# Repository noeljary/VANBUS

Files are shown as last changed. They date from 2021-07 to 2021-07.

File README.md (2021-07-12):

# VANBUS
Circuits and MCU Code for Camper Van Electronics Control Systems

VANBUS will be a series of circuit boards designed to control all electronic systems within a camper van conversion. It is based on a CANBUS network for inter-board communiciations.

This repository contains the Autodesk EAGLE files for the circuit boards, links to the custom designed cases, and the microcontroller code used to control the system.

Boards:
- LIGHTING_CTL_BOARD: Circuit Board for PWM Control of LED Lighting
- MOSFET_CTL_BOARD: Circuit Board for Fused Power Distribution with Voltage/Current per Channel Monitoring
- REMOTE_SWITCH_BOARD: Circuit Board for Remote Switching of MOSFET/Lighting Circuits with Momentary/Latched Switching, and Status Indication
- CAPACITIVE_SWITCH_BOARD: Circuit Board for Dimming Control of Lighting Circuits with Capacitive Touch Slider
- MOSFET_POC: Proof of Concept Circuit Board for MOSET based solid state relay system
- VANBUS_HUB: Circuit Board for Central Connection of CANBUS connectors where daisy chaining is not possible

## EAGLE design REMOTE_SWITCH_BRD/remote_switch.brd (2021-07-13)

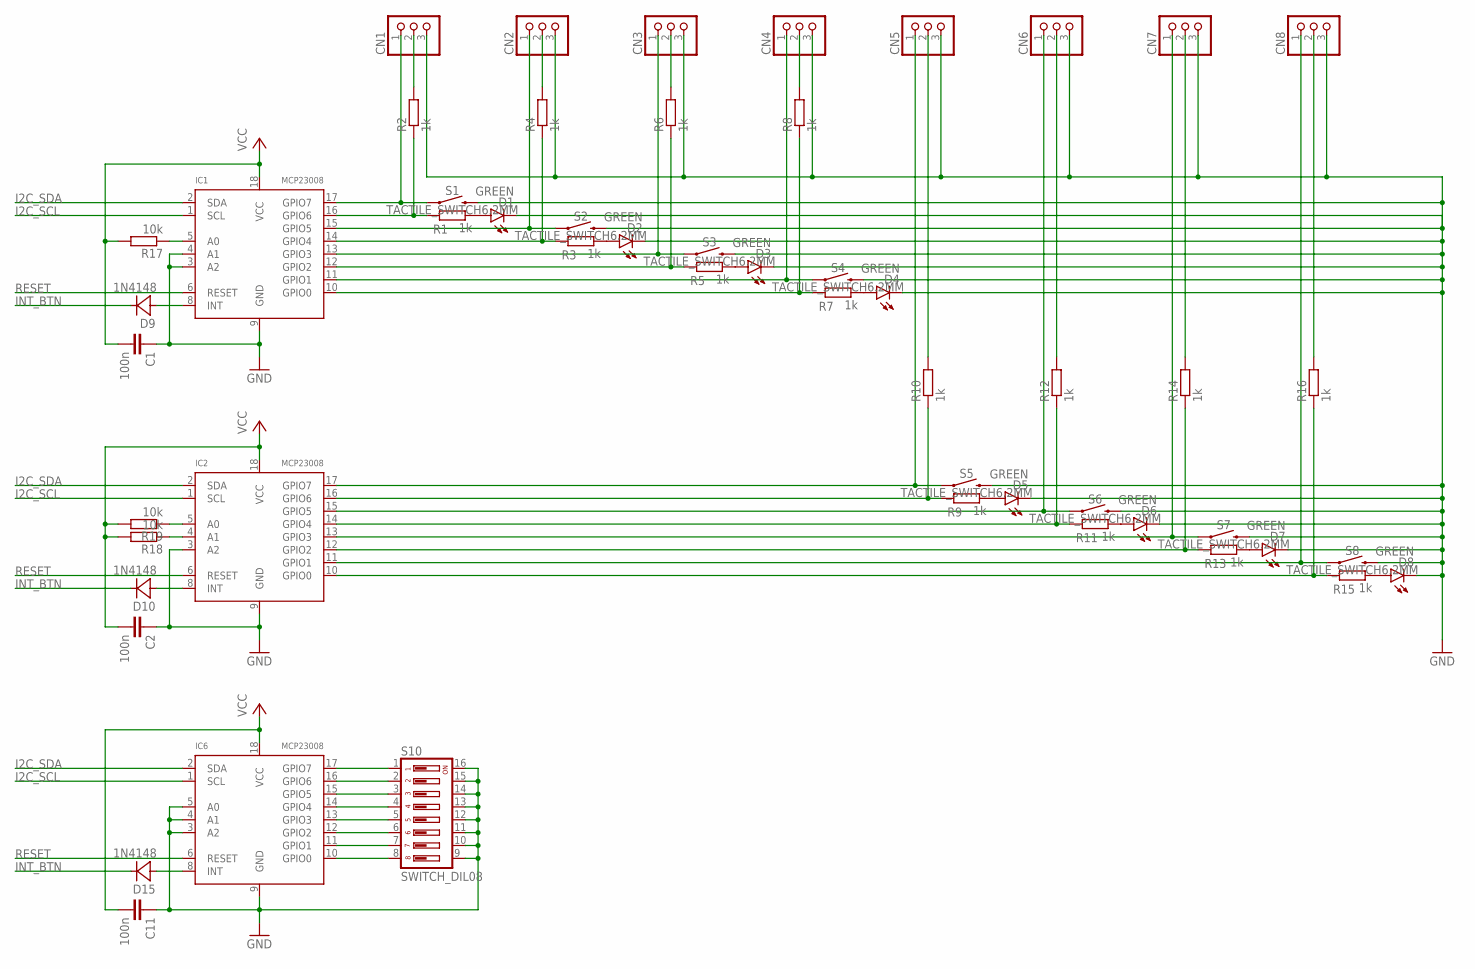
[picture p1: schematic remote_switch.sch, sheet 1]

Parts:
C1, C2, C11: 100n; C0805
CN1, CN2, CN3, CN4, CN5, CN6, CN7, CN8: JST_3PIN; JSTPH3
D1, D2, D3, D4, D5, D6, D7, D8: GREEN; CHIPLED_1206
D9, D10, D15: 1N4148; SOD123
IC1, IC2, IC6: MCP23008; SO18W
R1, R2, R3, R4, R5, R6, R7, R8, R9, R10, R11, R12, R13, R14, R15, R16: 1k; R0805
R17, R18, R19: 10k; R0805
S1, S2, S3, S4, S5, S6, S7, S8: TACTILE_SWITCH6.2MM; TACTILE_SWITCH_SMD_6.2MM
S10: SWITCH_DIL08; CTS-219-08

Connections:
GND: C1.1, C2.1, C11.1, CN1.3, CN2.3, CN3.3, CN4.3, CN5.3, CN6.3, CN7.3, CN8.3, D1.C, D2.C, D3.C, D4.C, D5.C, D6.C, D7.C, D8.C, IC1.3 (A2), IC1.4 (A1), IC1.9 (GND), IC2.3 (A2), IC2.9 (GND), IC6.3 (A2), IC6.4 (A1), IC6.5 (A0), IC6.9 (GND), S1.B1 (2), S1.B2 (2), S2.B1 (2), S2.B2 (2), S3.B1 (2), S3.B2 (2), S4.B1 (2), S4.B2 (2), S5.B1 (2), S5.B2 (2), S6.B1 (2), S6.B2 (2), S7.B1 (2), S7.B2 (2), S8.B1 (2), S8.B2 (2), S10.9, S10.10, S10.11, S10.12, S10.13, S10.14, S10.15, S10.16; also elsewhere on the board
I2C_SCL: IC1.1 (SCL), IC2.1 (SCL), IC6.1 (SCL); also elsewhere on the board
I2C_SDA: IC1.2 (SDA), IC2.2 (SDA), IC6.2 (SDA); also elsewhere on the board
INT_BTN: D9.C, D10.C, D15.C; also elsewhere on the board
unnamed: IC1.5 (A0), R17.1
unnamed: IC2.5 (A0), R19.1
unnamed: IC2.4 (A1), R18.1
unnamed: IC6.17 (GPIO7), S10.1
unnamed: IC6.16 (GPIO6), S10.2
unnamed: IC6.15 (GPIO5), S10.3
unnamed: IC6.14 (GPIO4), S10.4
unnamed: IC6.13 (GPIO3), S10.5
unnamed: IC6.12 (GPIO2), S10.6
unnamed: IC6.11 (GPIO1), S10.7
unnamed: CN1.1, IC1.17 (GPIO7), S1.A1 (1), S1.A2 (1)
unnamed: CN2.1, IC1.15 (GPIO5), S2.A1 (1), S2.A2 (1)
unnamed: CN3.1, IC1.13 (GPIO3), S3.A1 (1), S3.A2 (1)
unnamed: CN4.1, IC1.11 (GPIO1), S4.A1 (1), S4.A2 (1)
unnamed: CN5.1, IC2.17 (GPIO7), S5.A1 (1), S5.A2 (1)
unnamed: CN6.1, IC2.15 (GPIO5), S6.A1 (1), S6.A2 (1)
unnamed: CN7.1, IC2.13 (GPIO3), S7.A1 (1), S7.A2 (1)
unnamed: CN8.1, IC2.11 (GPIO1), S8.A1 (1), S8.A2 (1)
unnamed: D1.A, R1.2
unnamed: D2.A, R3.2
unnamed: D3.A, R5.2
unnamed: D4.A, R7.2
unnamed: D5.A, R9.2
unnamed: D6.A, R11.2
unnamed: D7.A, R13.2
unnamed: D8.A, R15.2
unnamed: CN1.2, R2.2
unnamed: IC1.16 (GPIO6), R1.1, R2.1
unnamed: CN2.2, R4.2
unnamed: CN3.2, R6.2
unnamed: CN4.2, R8.2
unnamed: CN5.2, R10.2
unnamed: CN6.2, R12.2
unnamed: CN7.2, R14.2
unnamed: CN8.2, R16.2
unnamed: IC1.14 (GPIO4), R3.1, R4.1
unnamed: IC1.12 (GPIO2), R5.1, R6.1
unnamed: IC1.10 (GPIO0), R7.1, R8.1
unnamed: IC2.16 (GPIO6), R9.1, R10.1
unnamed: IC2.14 (GPIO4), R11.1, R12.1
unnamed: IC2.12 (GPIO2), R13.1, R14.1
unnamed: IC2.10 (GPIO0), R15.1, R16.1
unnamed: IC6.10 (GPIO0), S10.8
unnamed: D10.A, IC2.8 (INT)
unnamed: D9.A, IC1.8 (INT)
unnamed: D15.A, IC6.8 (INT)
RESET: IC1.6 (RESET), IC2.6 (RESET), IC6.6 (RESET); also elsewhere on the board
VCC: C1.2, C2.2, C11.2, IC1.18 (VCC), IC2.18 (VCC), IC6.18 (VCC), R17.2, R18.2, R19.2; also elsewhere on the board

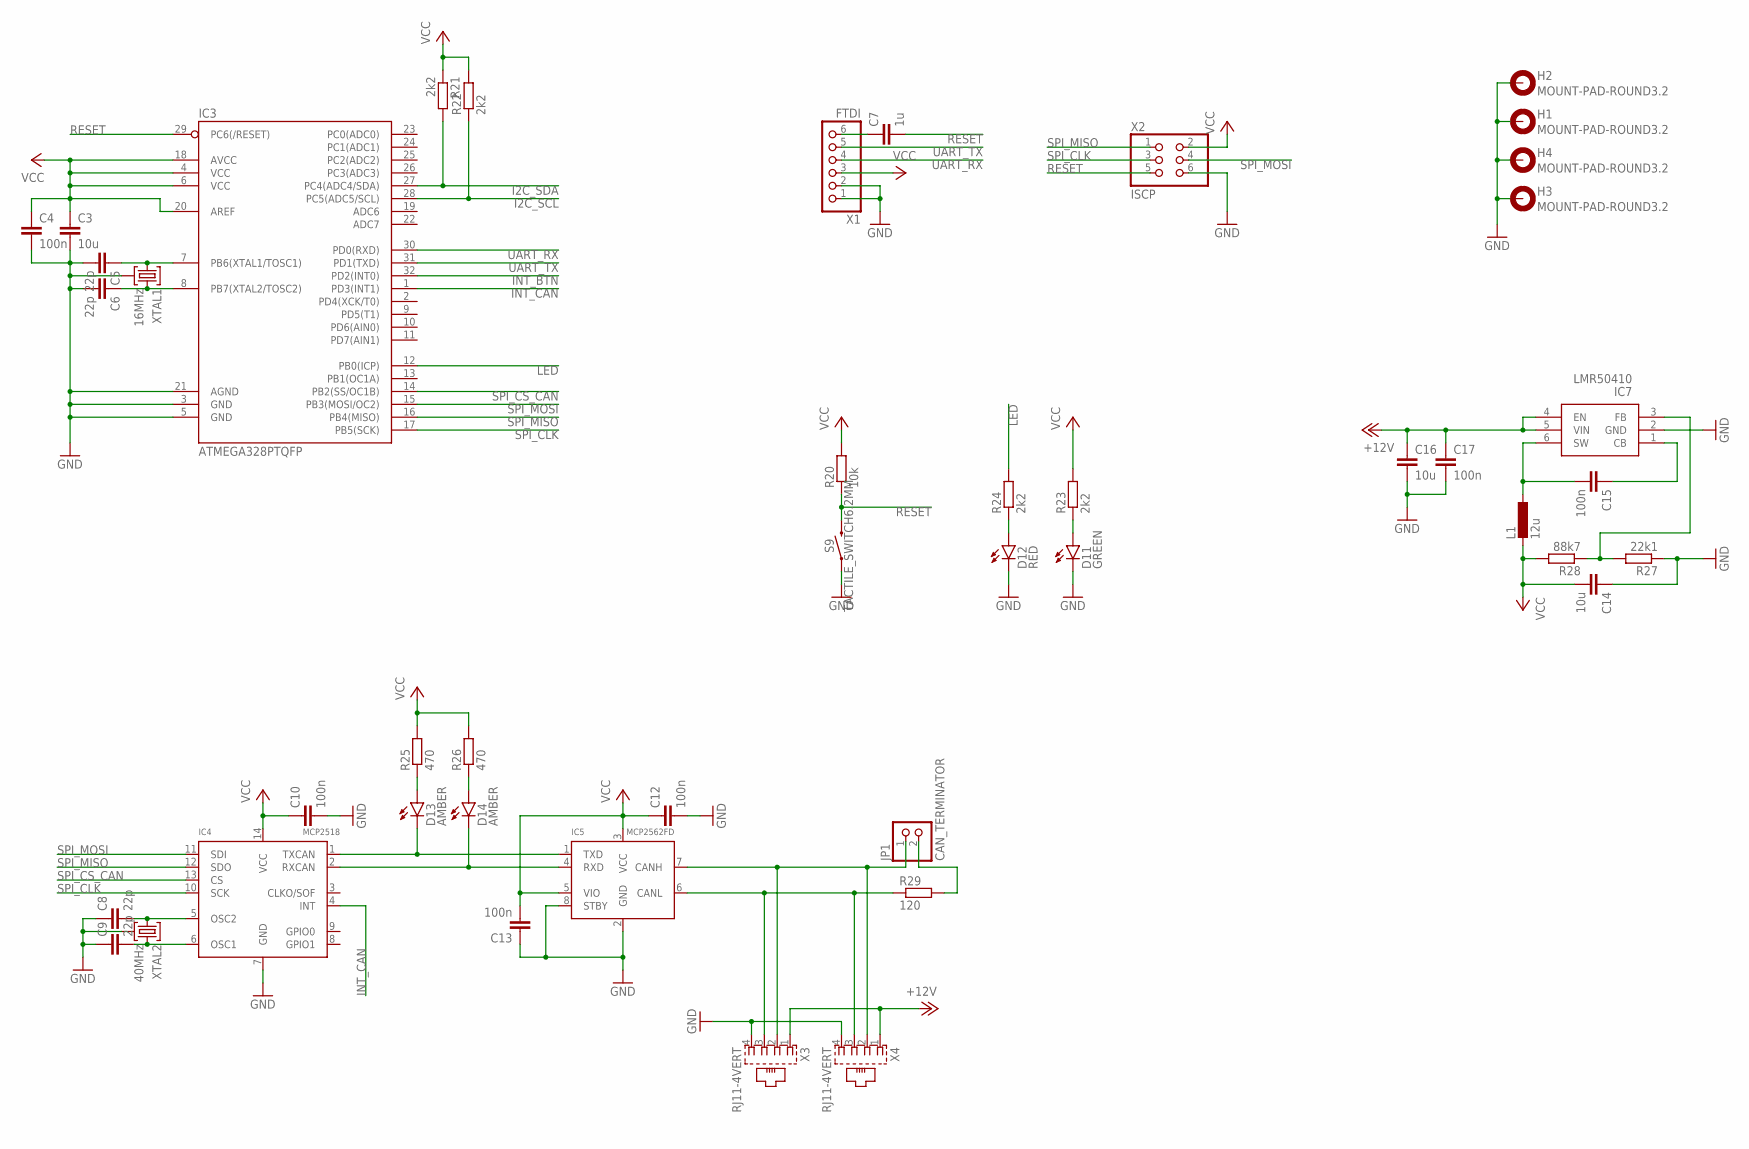
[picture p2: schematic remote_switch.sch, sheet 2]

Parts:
C3, C14, C16: 10u; C1206
C4, C10, C12, C13, C15, C17: 100n; C0805
C5, C6, C8, C9: 22p; C0805
C7: 1u; C0805
D11: GREEN; CHIPLED_1206
D12: RED; CHIPLED_1206
D13, D14: AMBER; CHIPLED_1206
H1, H2, H3, H4: MOUNT-PAD-ROUND3.2; 3,2-PAD
IC3: ATMEGA328PTQFP; TQFP32_0.8MM_7X7MM
IC4: MCP2518; SO14
IC5: MCP2562FD; SO08
IC7: LMR50410; SOT23-6
JP1: CAN_TERMINATOR; 1X02
L1: 12u; L_7.3MM
R20: 10k; R0805
R21, R22, R23, R24: 2k2; R0805
R25, R26: 470; R0805
R27: 22k1; R0805
R28: 88k7; R0805
R29: 120; R0805
S9: TACTILE_SWITCH6.2MM; TACTILE_SWITCH_SMD_6.2MM
X1: FTDI; 1X06
X2: ISCP; 2X03
X3, X4: RJ11-4VERT; RJ11-4_VERT
XTAL1: 16MHz; XTAL_5.0X3.2_4
XTAL2: 40MHz; XTAL_5.0X3.2_4

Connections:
+12V: C16.1, C17.1, IC7.4 (EN), IC7.5 (VIN), X3.1, X4.1
GND: C3.2, C4.2, C5.2, C6.2, C8.1, C9.1, C10.2, C12.2, C13.1, C14.1, C16.2, C17.2, D11.C, D12.C, H1.B3,2, H1.P$1, H1.P$2, H1.P$3, H1.P$4, H1.P$5, H1.P$6, H1.P$7, H1.P$8, H2.B3,2, H2.P$1, H2.P$2, H2.P$3, H2.P$4, H2.P$5, H2.P$6, H2.P$7, H2.P$8, H3.B3,2, H3.P$1, H3.P$2, H3.P$3, H3.P$4, H3.P$5, H3.P$6, H3.P$7, H3.P$8, H4.B3,2, H4.P$1, H4.P$2, H4.P$3, H4.P$4, H4.P$5, H4.P$6, H4.P$7, H4.P$8, IC3.3 (GND), IC3.5 (GND), IC3.21 (AGND), IC4.7 (GND), IC5.2 (GND), IC5.8 (STBY), IC7.2 (GND), R27.1, S9.A1 (1), S9.A2 (1), X1.1, X1.2, X2.6, X3.4, X4.4, XTAL1.2, XTAL1.4 (2), XTAL2.2, XTAL2.4 (2); also elsewhere on the board
I2C_SCL: IC3.28 (PC5(ADC5/SCL)), R22.1; also elsewhere on the board
I2C_SDA: IC3.27 (PC4(ADC4/SDA)), R21.2; also elsewhere on the board
INT_BTN: IC3.32 (PD2(INT0)); also elsewhere on the board
INT_CAN: IC3.1 (PD3(INT1)), IC4.4 (INT)
LED: IC3.12 (PB0(ICP)), R24.2
unnamed: D12.A, R24.1
unnamed: C5.1, IC3.7 (PB6(XTAL1/TOSC1)), XTAL1.1
unnamed: C6.1, IC3.8 (PB7(XTAL2/TOSC2)), XTAL1.3
unnamed: D11.A, R23.1
unnamed: C7.1, X1.6
unnamed: IC5.6 (CANL), R29.1, X3.3, X4.3
unnamed: IC5.7 (CANH), JP1.1, X3.2, X4.2
unnamed: D13.C, IC4.1 (TXCAN), IC5.1 (TXD)
unnamed: D14.C, IC4.2 (RXCAN), IC5.4 (RXD)
unnamed: C8.2, IC4.5 (OSC2), XTAL2.1
unnamed: C9.2, IC4.6 (OSC1), XTAL2.3
unnamed: D13.A, R25.1
unnamed: D14.A, R26.1
unnamed: JP1.2, R29.2
unnamed: C15.2, IC7.6 (SW), L1.1
unnamed: C15.1, IC7.1 (CB)
unnamed: IC7.3 (FB), R27.2, R28.1
RESET: C7.2, IC3.29 (PC6(/RESET)), R20.1, S9.B1 (2), S9.B2 (2), X2.5; also elsewhere on the board
SPI_CLK: IC3.17 (PB5(SCK)), IC4.10 (SCK), X2.3
SPI_CS_CAN: IC3.14 (PB2(SS/OC1B)), IC4.13 (CS)
SPI_MISO: IC3.16 (PB4(MISO)), IC4.12 (SDO), X2.1
SPI_MOSI: IC3.15 (PB3(MOSI/OC2)), IC4.11 (SDI), X2.4
UART_RX: IC3.30 (PD0(RXD)), X1.4
UART_TX: IC3.31 (PD1(TXD)), X1.5
VCC: C3.1, C4.1, C10.1, C12.1, C13.2, C14.2, IC3.4 (VCC), IC3.6 (VCC), IC3.18 (AVCC), IC3.20 (AREF), IC4.14 (VCC), IC5.3 (VCC), IC5.5 (VIO), L1.2, R20.2, R21.1, R22.2, R23.2, R25.2, R26.2, R28.2, X1.3, X2.2; also elsewhere on the board

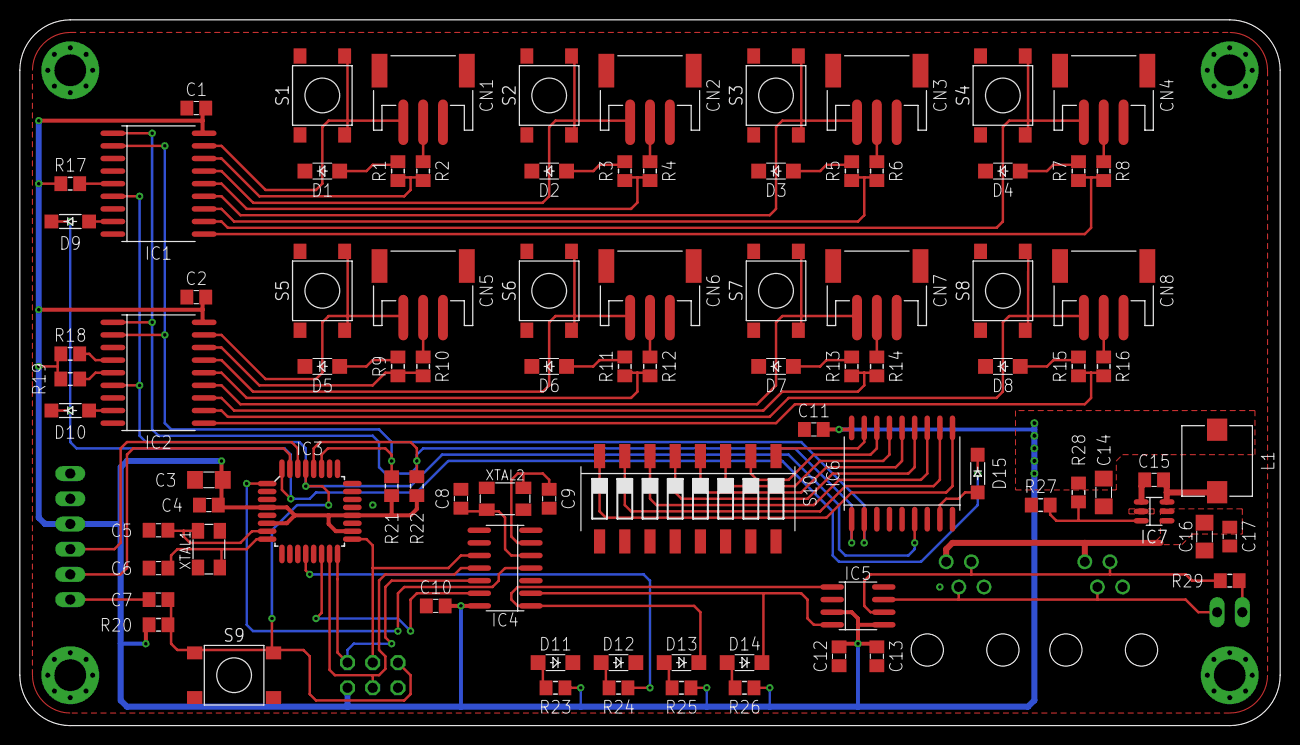
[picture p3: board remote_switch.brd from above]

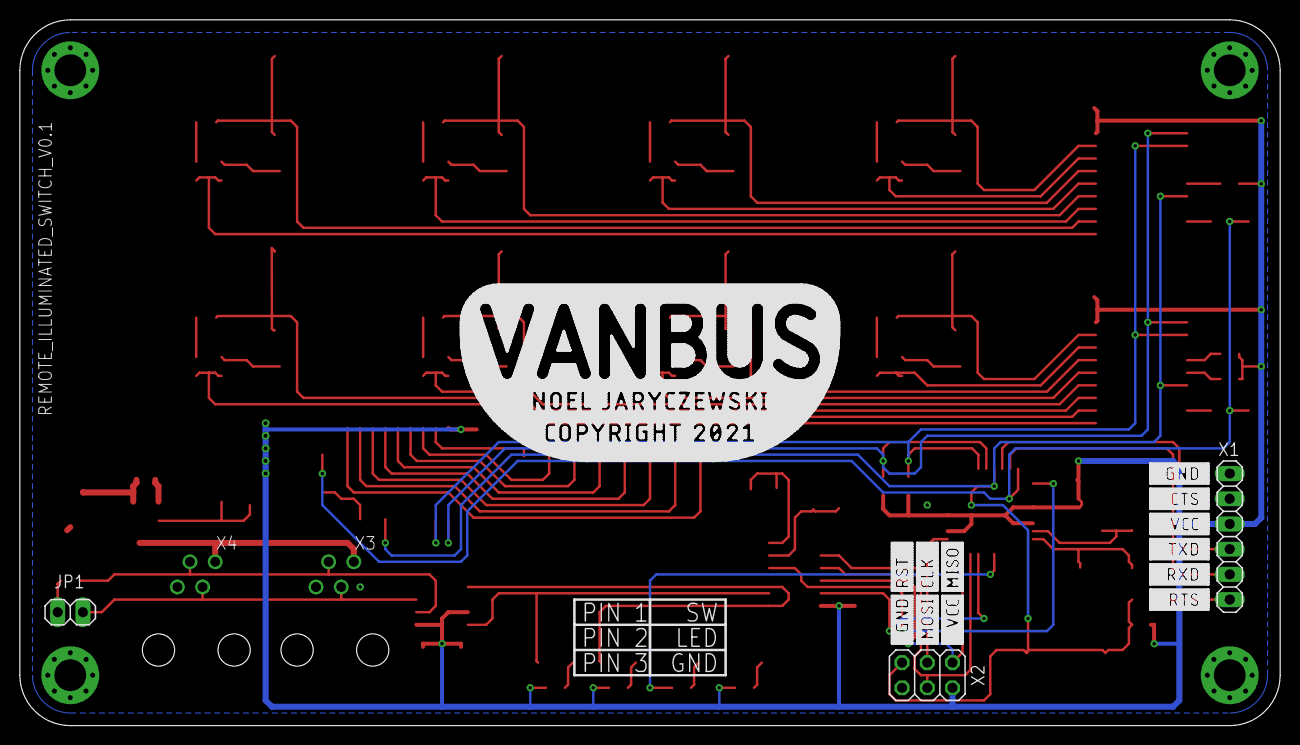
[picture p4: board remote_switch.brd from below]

Board: 2 copper layers, 127.0 x 71.1 mm, 98 parts (5 on the bottom side), 78 nets.

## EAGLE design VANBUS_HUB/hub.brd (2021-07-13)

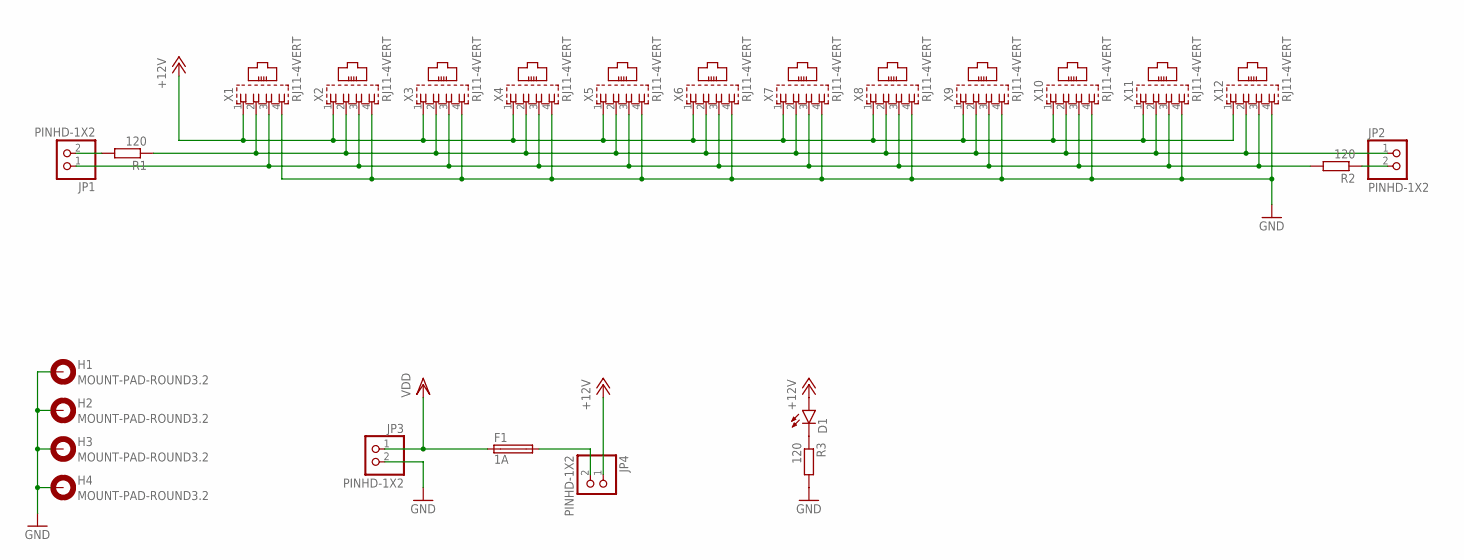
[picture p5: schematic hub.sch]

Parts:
D1: LED1206; CHIPLED_1206
F1: 1A; 5X20_FUSE
H1, H2, H3, H4: MOUNT-PAD-ROUND3.2; 3,2-PAD
JP1, JP2, JP3, JP4: PINHD-1X2; 1X02
R1, R2, R3: 120; R0805
X1, X2, X3, X4, X5, X6, X7, X8, X9, X10, X11, X12: RJ11-4VERT; RJ11-4_VERT

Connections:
+12V: D1.A, JP4.1, X1.1, X2.1, X3.1, X4.1, X5.1, X6.1, X7.1, X8.1, X9.1, X10.1, X11.1, X12.1
GND: H1.B3,2, H1.P$1, H1.P$2, H1.P$3, H1.P$4, H1.P$5, H1.P$6, H1.P$7, H1.P$8, H2.B3,2, H2.P$1, H2.P$2, H2.P$3, H2.P$4, H2.P$5, H2.P$6, H2.P$7, H2.P$8, H3.B3,2, H3.P$1, H3.P$2, H3.P$3, H3.P$4, H3.P$5, H3.P$6, H3.P$7, H3.P$8, H4.B3,2, H4.P$1, H4.P$2, H4.P$3, H4.P$4, H4.P$5, H4.P$6, H4.P$7, H4.P$8, JP3.2, R3.2, X1.4, X2.4, X3.4, X4.4, X5.4, X6.4, X7.4, X8.4, X9.4, X10.4, X11.4, X12.4
unnamed: JP2.2, R2.1
unnamed: JP2.1, R1.1, X1.2, X2.2, X3.2, X4.2, X5.2, X6.2, X7.2, X8.2, X9.2, X10.2, X11.2, X12.2
unnamed: JP1.1, R2.2, X1.3, X2.3, X3.3, X4.3, X5.3, X6.3, X7.3, X8.3, X9.3, X10.3, X11.3, X12.3
unnamed: JP1.2, R1.2
unnamed: D1.C, R3.1
unnamed: F1.2A (2), F1.2B (2), JP4.2
VDD: F1.1A (1), F1.1B (1), JP3.1

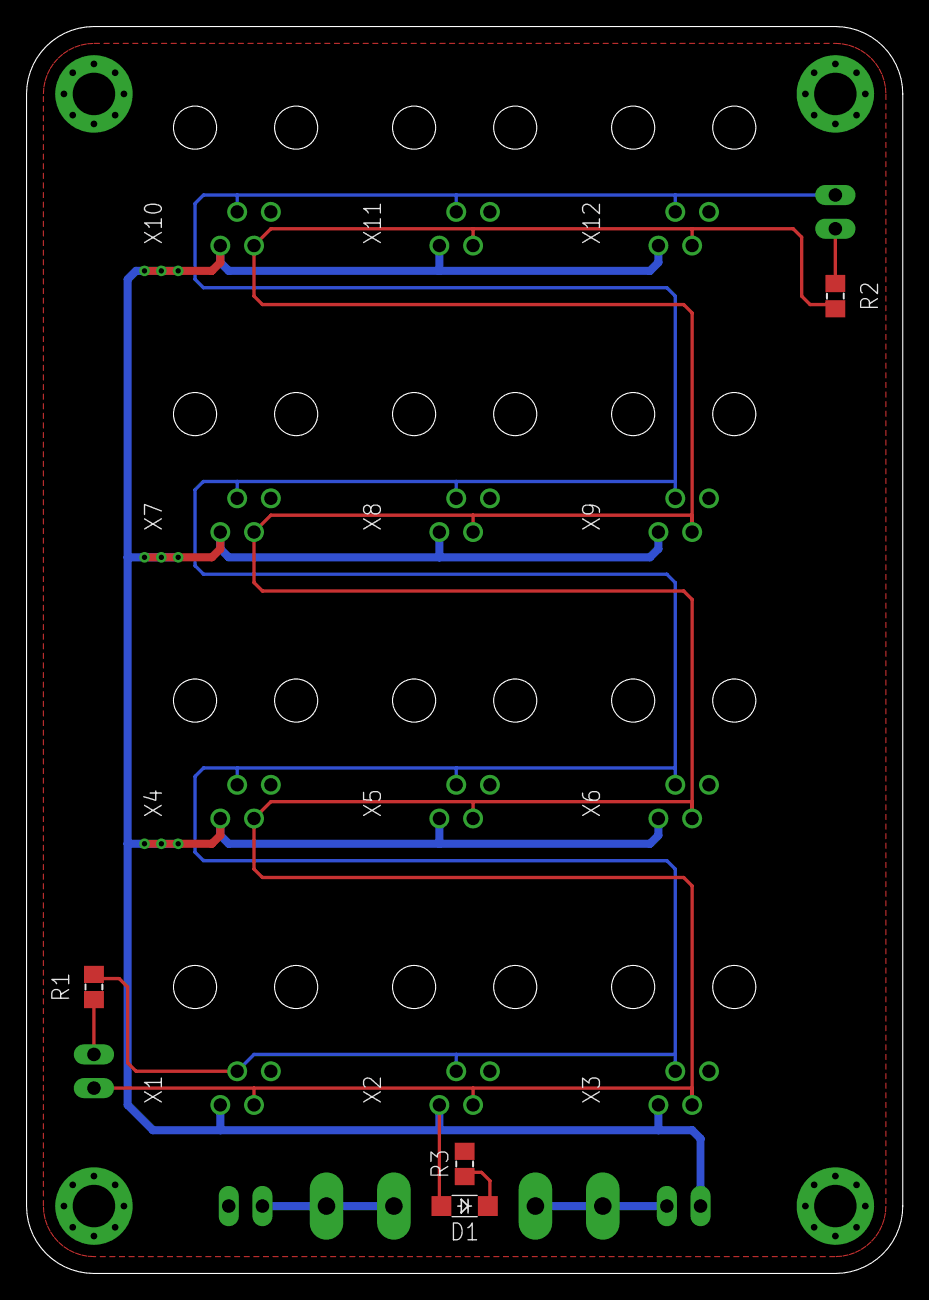
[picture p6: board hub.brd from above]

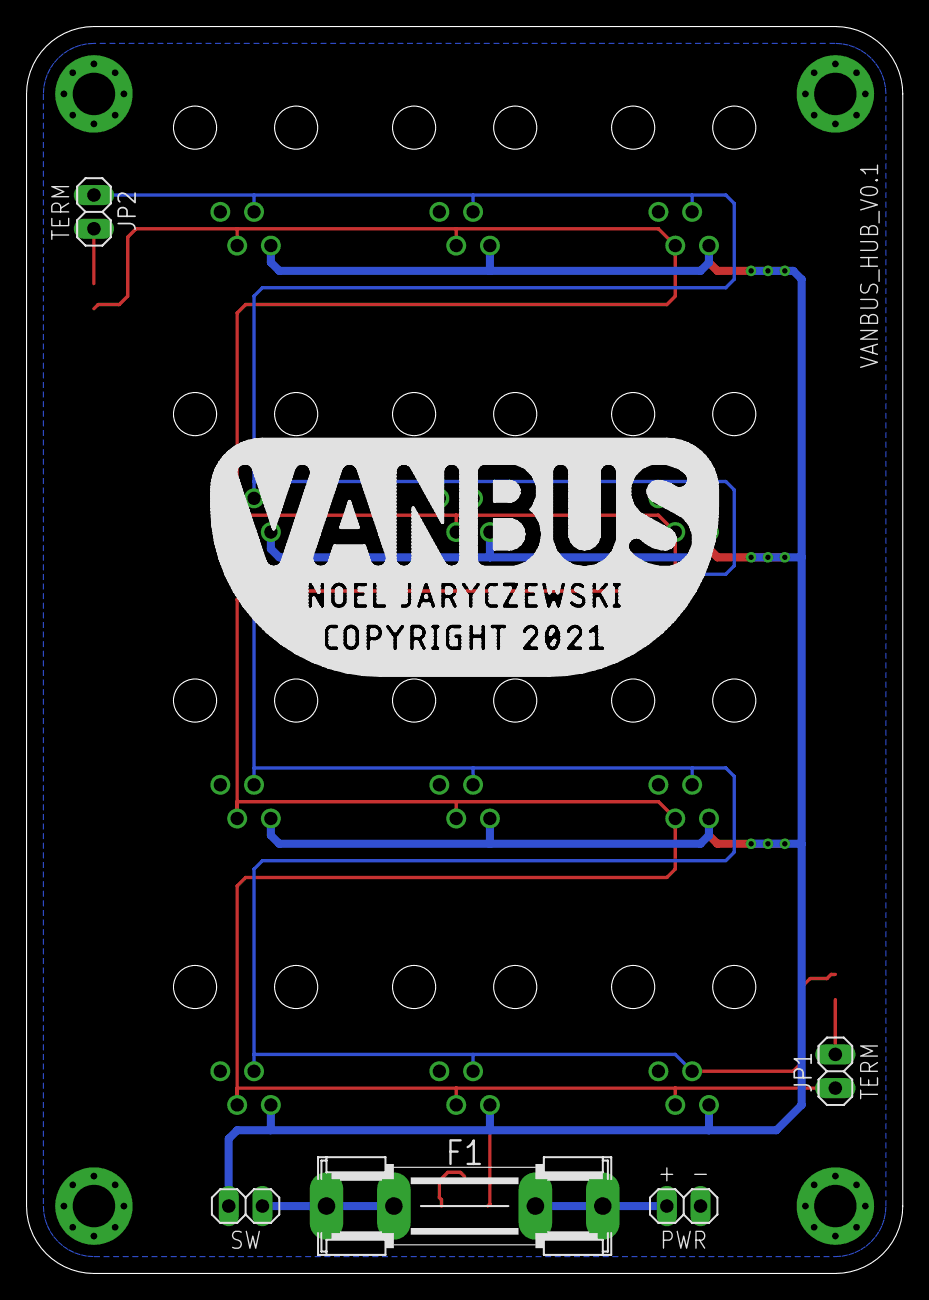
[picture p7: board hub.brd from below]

Board: 2 copper layers, 66.0 x 94.0 mm, 25 parts (5 on the bottom side), 9 nets.

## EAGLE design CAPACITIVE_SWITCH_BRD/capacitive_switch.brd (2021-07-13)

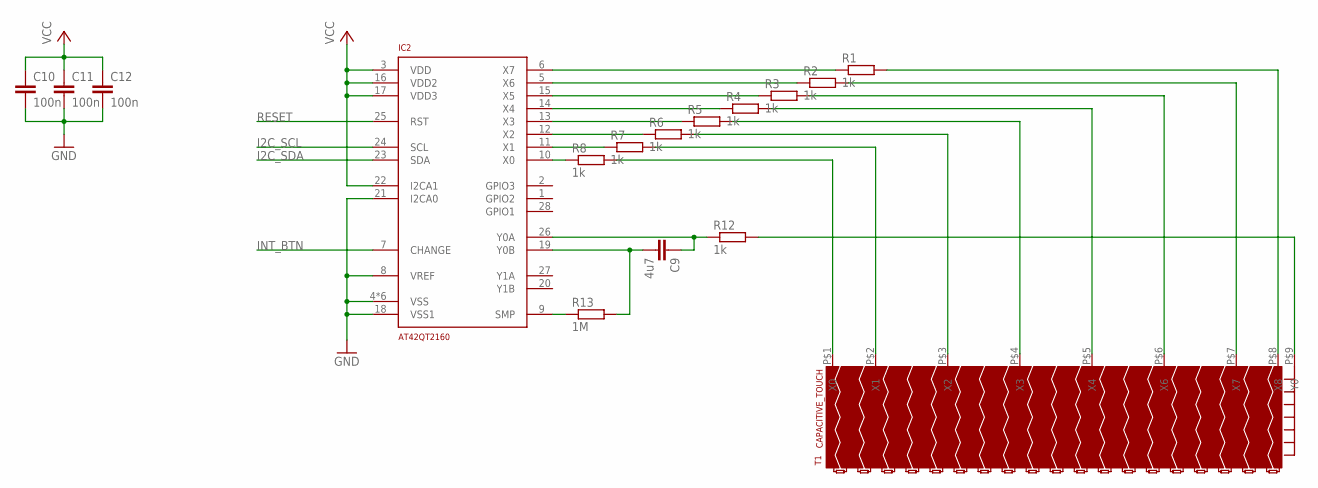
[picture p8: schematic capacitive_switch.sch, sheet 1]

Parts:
C9: 4u7; C0805
C10, C11, C12: 100n; C0805
IC2: AT42QT2160; QFN28_0.45MM_4X4MM
R1, R2, R3, R4, R5, R6, R7, R8, R12: 1k; R0805
R13: 1M; R0805
T1: CAPACITIVE_TOUCH; 90X20_CAPACITIVE_TOUCH

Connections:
GND: C10.2, C11.2, C12.2, IC2.4 (VSS), IC2.8 (VREF), IC2.18 (VSS1), IC2.21 (I2CA0), IC2.29 (VSS), IC2.P$1 (VSS), IC2.P$2 (VSS), IC2.P$3 (VSS), IC2.P$4 (VSS); also elsewhere on the board
I2C_SCL: IC2.24 (SCL); also elsewhere on the board
I2C_SDA: IC2.23 (SDA); also elsewhere on the board
INT_BTN: IC2.7 (CHANGE); also elsewhere on the board
unnamed: R8.2, T1.P$1 (X0)
unnamed: R7.2, T1.P$2 (X1)
unnamed: R6.2, T1.P$3 (X2)
unnamed: R5.2, T1.P$4 (X3)
unnamed: R4.2, T1.P$5 (X4)
unnamed: R3.2, T1.P$6 (X6)
unnamed: R2.2, T1.P$7 (X7)
unnamed: R1.2, T1.P$8 (X8)
unnamed: R12.2, T1.P$9 (Y0)
unnamed: C9.1, IC2.26 (Y0A), R12.1
unnamed: IC2.10 (X0), R8.1
unnamed: IC2.11 (X1), R7.1
unnamed: IC2.12 (X2), R6.1
unnamed: IC2.13 (X3), R5.1
unnamed: IC2.14 (X4), R4.1
unnamed: IC2.15 (X5), R3.1
unnamed: IC2.5 (X6), R2.1
unnamed: IC2.6 (X7), R1.1
unnamed: C9.2, IC2.19 (Y0B), R13.2
unnamed: IC2.9 (SMP), R13.1
RESET: IC2.25 (RST); also elsewhere on the board
VCC: C10.1, C11.1, C12.1, IC2.3 (VDD), IC2.16 (VDD2), IC2.17 (VDD3), IC2.22 (I2CA1); also elsewhere on the board

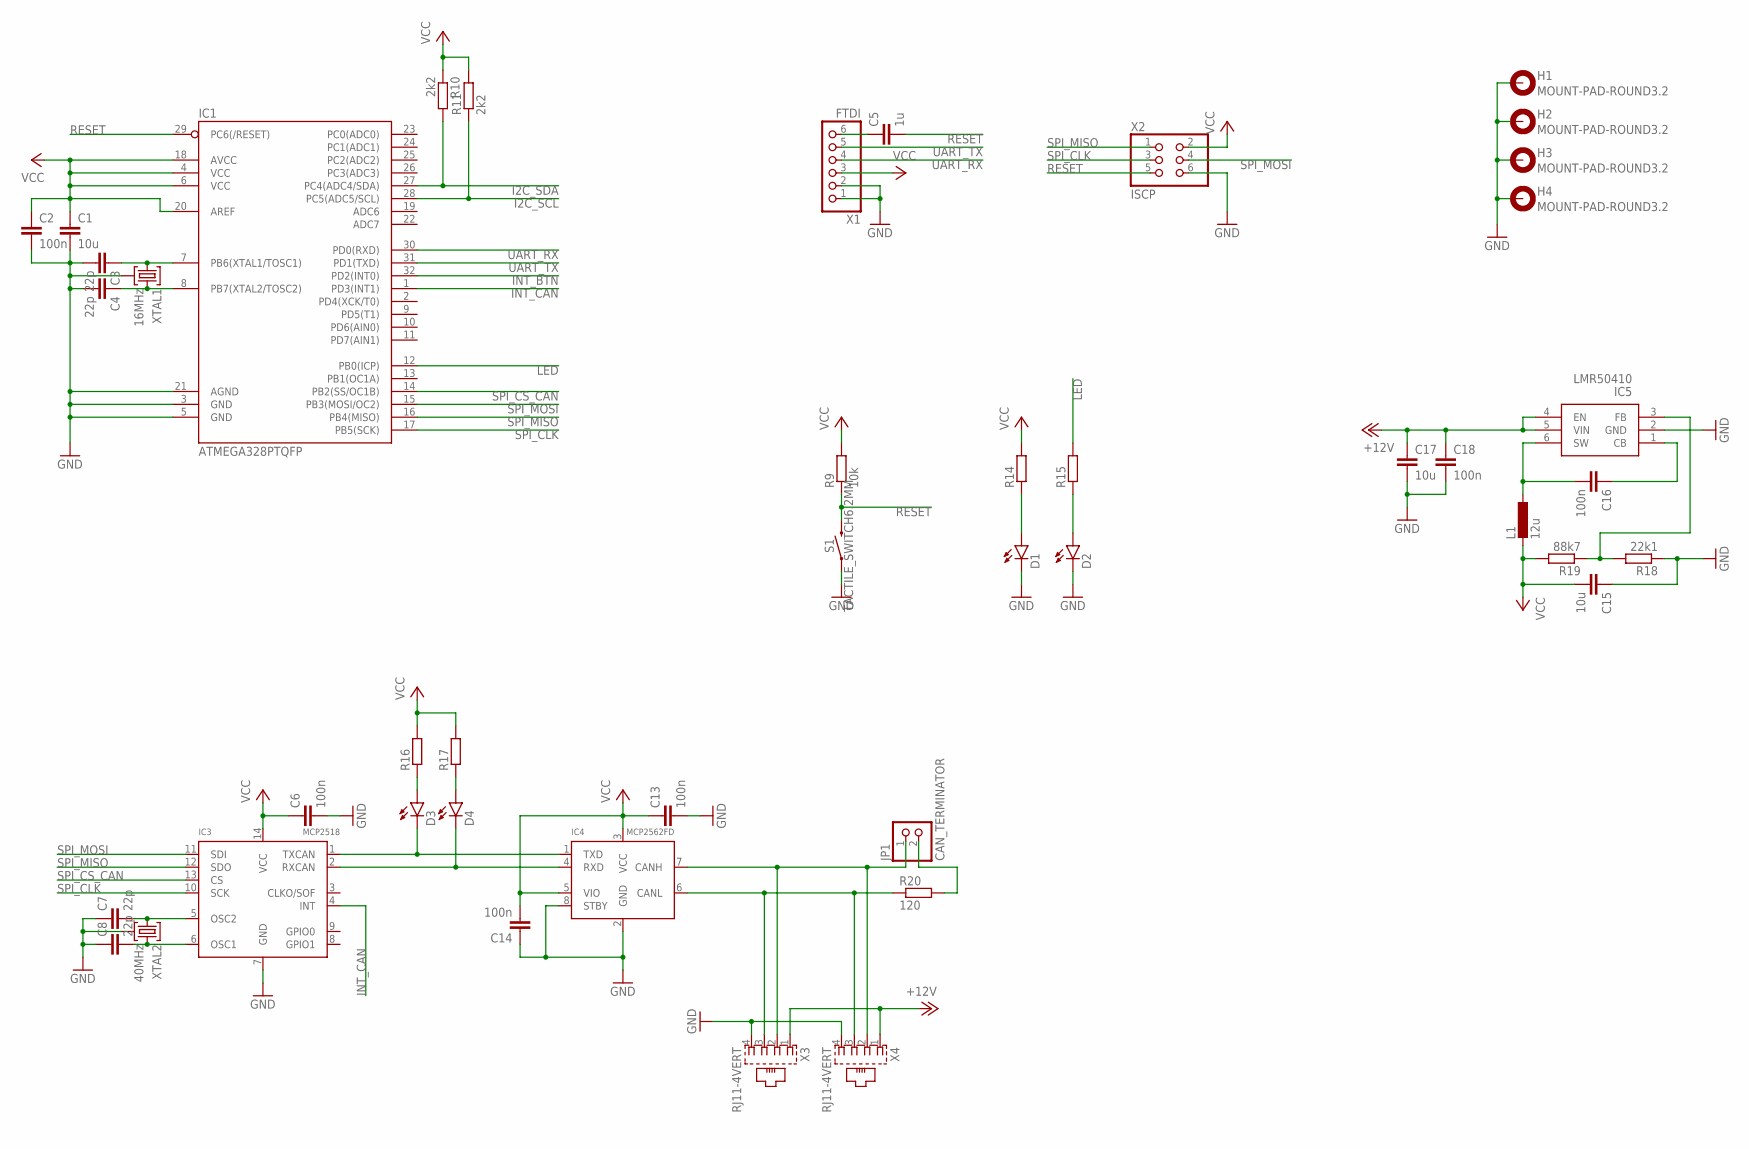
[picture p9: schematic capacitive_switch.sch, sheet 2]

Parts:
C1, C15, C17: 10u; C1206
C2, C6, C13, C14, C16, C18: 100n; C0805
C3, C4, C7, C8: 22p; C0805
C5: 1u; C0805
D1, D2, D3, D4: LED1206; CHIPLED_1206
H1, H2, H3, H4: MOUNT-PAD-ROUND3.2; 3,2-PAD
IC1: ATMEGA328PTQFP; TQFP32_0.8MM_7X7MM
IC3: MCP2518; SO14
IC4: MCP2562FD; SO08
IC5: LMR50410; SOT23-6
JP1: CAN_TERMINATOR; 1X02
L1: 12u; L_7.3MM
R9: 10k; R0805
R10, R11: 2k2; R0805
R14, R15, R16, R17: RESISTOR0805; R0805
R18: 22k1; R0805
R19: 88k7; R0805
R20: 120; R0805
S1: TACTILE_SWITCH6.2MM; TACTILE_SWITCH_SMD_6.2MM
X1: FTDI; 1X06
X2: ISCP; 2X03
X3, X4: RJ11-4VERT; RJ11-4_VERT
XTAL1: 16MHz; XTAL_5.0X3.2_4
XTAL2: 40MHz; XTAL_5.0X3.2_4

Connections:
+12V: C17.1, C18.1, IC5.4 (EN), IC5.5 (VIN), X3.1, X4.1
GND: C1.2, C2.2, C3.2, C4.2, C6.2, C7.1, C8.1, C13.2, C14.1, C15.1, C17.2, C18.2, D1.C, D2.C, H1.B3,2, H1.P$1, H1.P$2, H1.P$3, H1.P$4, H1.P$5, H1.P$6, H1.P$7, H1.P$8, H2.B3,2, H2.P$1, H2.P$2, H2.P$3, H2.P$4, H2.P$5, H2.P$6, H2.P$7, H2.P$8, H3.B3,2, H3.P$1, H3.P$2, H3.P$3, H3.P$4, H3.P$5, H3.P$6, H3.P$7, H3.P$8, H4.B3,2, H4.P$1, H4.P$2, H4.P$3, H4.P$4, H4.P$5, H4.P$6, H4.P$7, H4.P$8, IC1.3 (GND), IC1.5 (GND), IC1.21 (AGND), IC3.7 (GND), IC4.2 (GND), IC4.8 (STBY), IC5.2 (GND), R18.1, S1.A1 (1), S1.A2 (1), X1.1, X1.2, X2.6, X3.4, X4.4, XTAL1.2, XTAL1.4 (2), XTAL2.2, XTAL2.4 (2); also elsewhere on the board
I2C_SCL: IC1.28 (PC5(ADC5/SCL)), R11.1; also elsewhere on the board
I2C_SDA: IC1.27 (PC4(ADC4/SDA)), R10.2; also elsewhere on the board
INT_BTN: IC1.32 (PD2(INT0)); also elsewhere on the board
INT_CAN: IC1.1 (PD3(INT1)), IC3.4 (INT)
LED: IC1.12 (PB0(ICP)), R15.2
unnamed: D3.A, R16.1
unnamed: C3.1, IC1.7 (PB6(XTAL1/TOSC1)), XTAL1.1
unnamed: C4.1, IC1.8 (PB7(XTAL2/TOSC2)), XTAL1.3
unnamed: D4.A, R17.1
unnamed: C5.1, X1.6
unnamed: IC4.6 (CANL), R20.1, X3.3, X4.3
unnamed: IC4.7 (CANH), JP1.1, X3.2, X4.2
unnamed: D3.C, IC3.1 (TXCAN), IC4.1 (TXD)
unnamed: D4.C, IC3.2 (RXCAN), IC4.4 (RXD)
unnamed: C7.2, IC3.5 (OSC2), XTAL2.1
unnamed: C8.2, IC3.6 (OSC1), XTAL2.3
unnamed: D1.A, R14.1
unnamed: D2.A, R15.1
unnamed: JP1.2, R20.2
unnamed: C16.2, IC5.6 (SW), L1.1
unnamed: C16.1, IC5.1 (CB)
unnamed: IC5.3 (FB), R18.2, R19.1
RESET: C5.2, IC1.29 (PC6(/RESET)), R9.1, S1.B1 (2), S1.B2 (2), X2.5; also elsewhere on the board
SPI_CLK: IC1.17 (PB5(SCK)), IC3.10 (SCK), X2.3
SPI_CS_CAN: IC1.14 (PB2(SS/OC1B)), IC3.13 (CS)
SPI_MISO: IC1.16 (PB4(MISO)), IC3.12 (SDO), X2.1
SPI_MOSI: IC1.15 (PB3(MOSI/OC2)), IC3.11 (SDI), X2.4
UART_RX: IC1.30 (PD0(RXD)), X1.4
UART_TX: IC1.31 (PD1(TXD)), X1.5
VCC: C1.1, C2.1, C6.1, C13.1, C14.2, C15.2, IC1.4 (VCC), IC1.6 (VCC), IC1.18 (AVCC), IC1.20 (AREF), IC3.14 (VCC), IC4.3 (VCC), IC4.5 (VIO), L1.2, R9.2, R10.1, R11.2, R14.2, R16.2, R17.2, R19.2, X1.3, X2.2; also elsewhere on the board

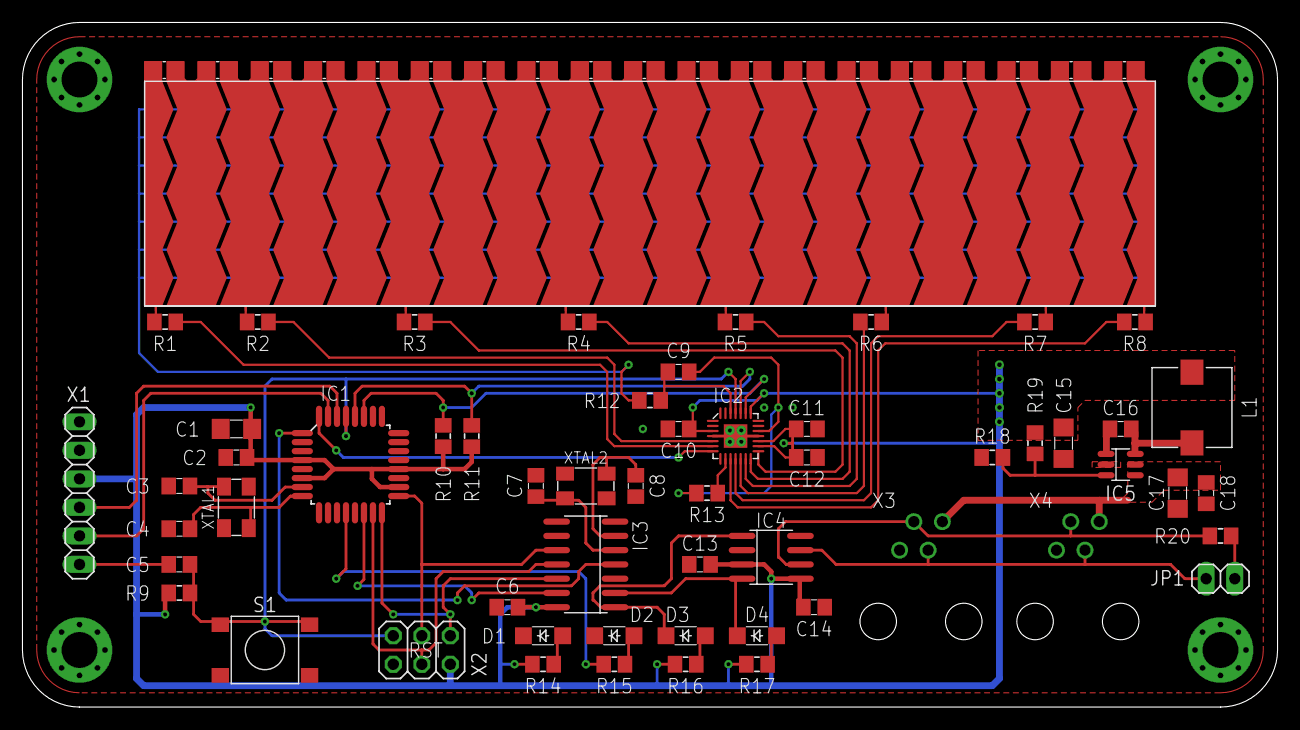
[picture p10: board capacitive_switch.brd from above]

Board: 2 copper layers, 111.8 x 61.0 mm, 61 parts (0 on the bottom side), 52 nets.

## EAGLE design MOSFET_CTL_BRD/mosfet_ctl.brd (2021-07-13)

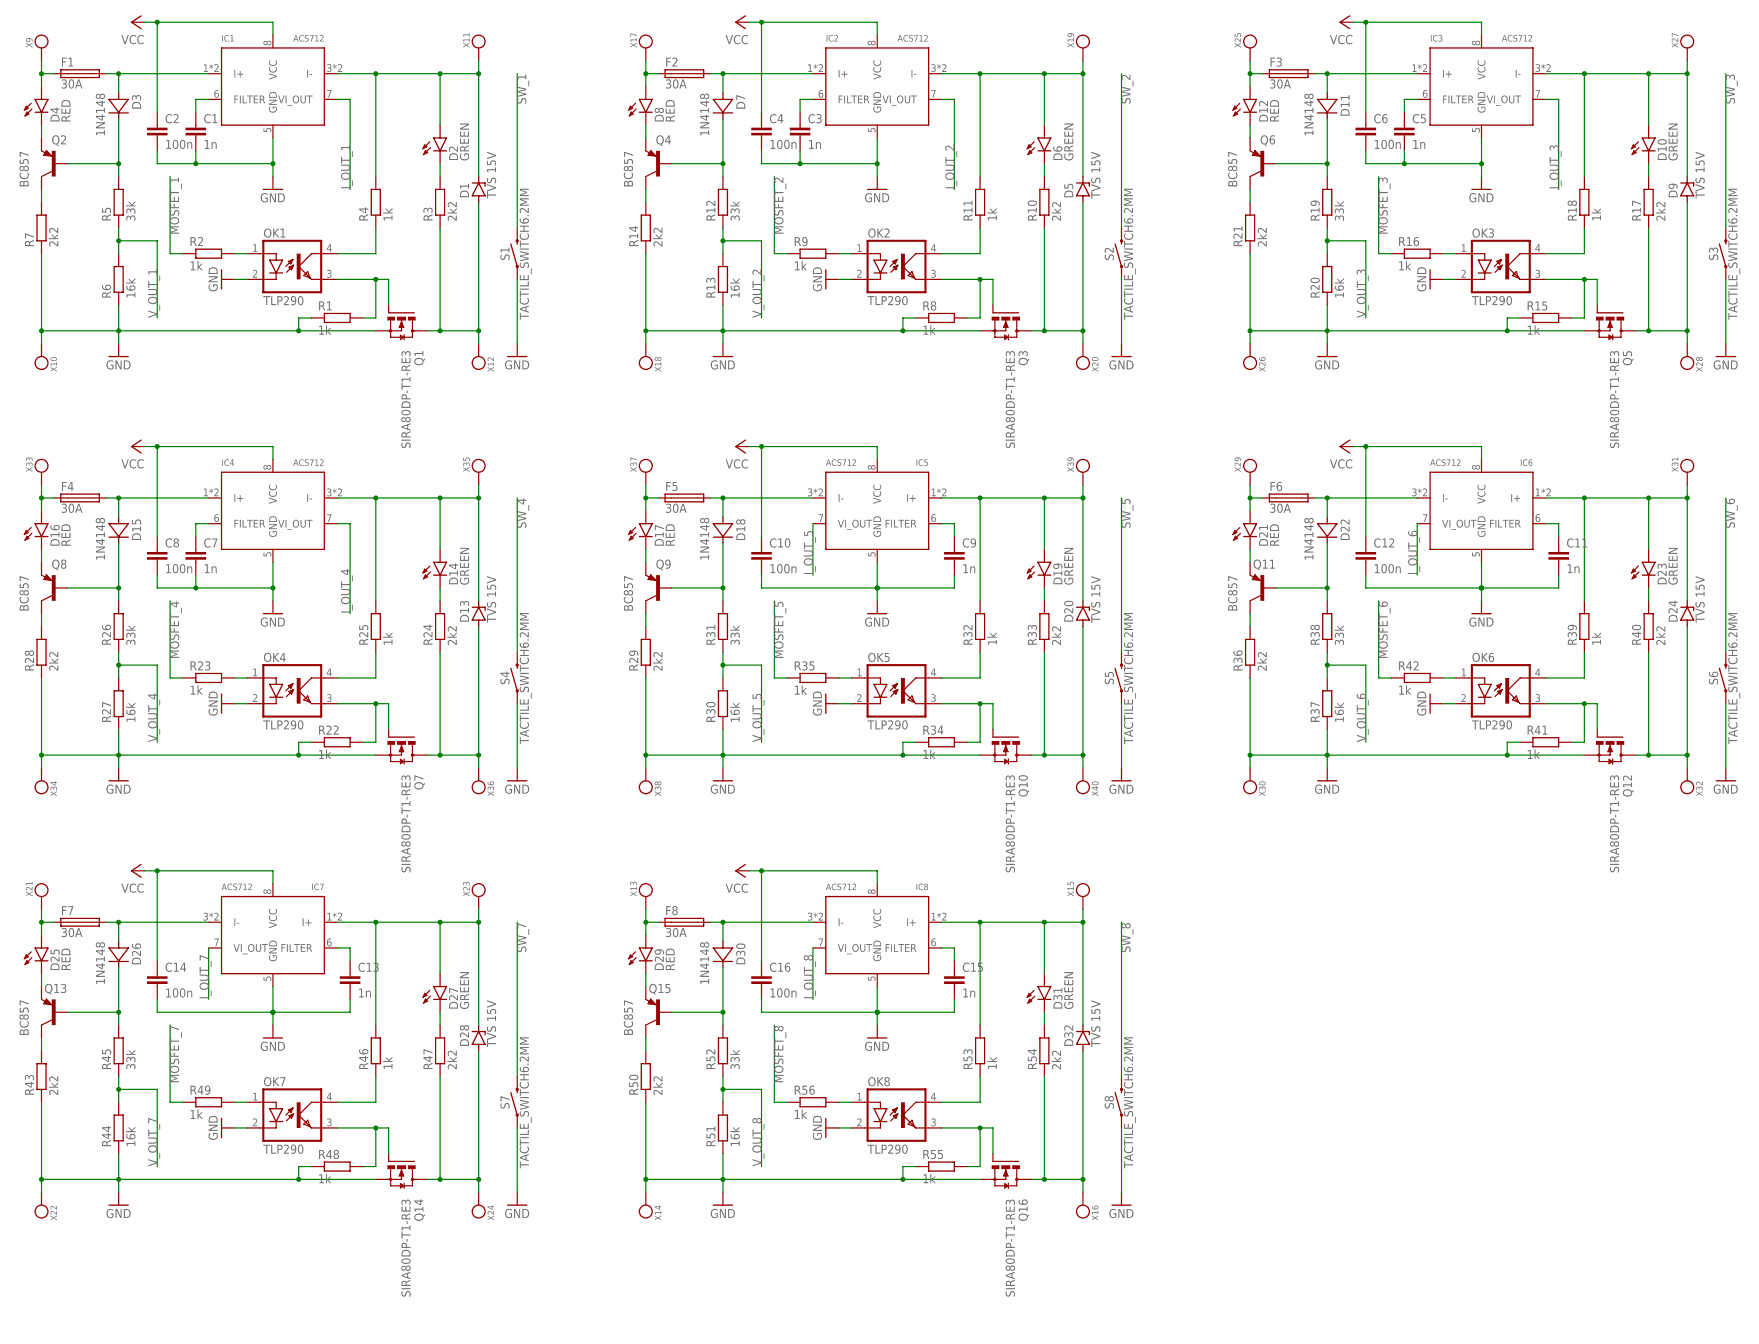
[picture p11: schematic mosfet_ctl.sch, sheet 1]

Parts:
C1, C3, C5, C7, C9, C11, C13, C15: 1n; C0805
C2, C4, C6, C8, C10, C12, C14, C16: 100n; C0805
D1, D5, D9, D13, D20, D24, D28, D32: TVS 15V; DO214AC
D2, D6, D10, D14, D19, D23, D27, D31: GREEN; CHIPLED_1206
D3, D7, D11, D15, D18, D22, D26, D30: 1N4148; SOD123
D4, D8, D12, D16, D17, D21, D25, D29: RED; CHIPLED_1206
F1, F2, F3, F4, F5, F6, F7, F8: 30A; KEYSTONE_3557-2
IC1, IC2, IC3, IC4, IC5, IC6, IC7, IC8: ACS712; SO08
OK1, OK2, OK3, OK4, OK5, OK6, OK7, OK8: TLP290; SO04
Q1, Q3, Q5, Q7, Q10, Q12, Q14, Q16: SIRA80DP-T1-RE3; POWERPAK-SO8
Q2, Q4, Q6, Q8, Q9, Q11, Q13, Q15: BC857; SOT23
R1, R2, R4, R8, R9, R11, R15, R16, R18, R22, R23, R25, R32, R34, R35, R39, R41, R42, R46, R48, R49, R53, R55, R56: 1k; R0805
R3, R7, R10, R14, R17, R21, R24, R28, R29, R33, R36, R40, R43, R47, R50, R54: 2k2; R0805
R5, R12, R19, R26, R31, R38, R45, R52: 33k; R0805
R6, R13, R20, R27, R30, R37, R44, R51: 16k; R0805
S1, S2, S3, S4, S5, S6, S7, S8: TACTILE_SWITCH6.2MM; TACTILE_SWITCH_SMD_6.2MM
X9, X10, X11, X12, X13, X14, X15, X16, X17, X18, X19, X20, X21, X22, X23, X24, X25, X26, X27, X28, X29, X30, X31, X32, X33, X34, X35, X36, X37, X38, X39, X40: KEYSTONE_7800

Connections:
GND: C1.2, C2.2, C3.2, C4.2, C5.2, C6.2, C7.2, C8.2, C9.2, C10.2, C11.2, C12.2, C13.2, C14.2, C15.2, C16.2, IC1.5 (GND), IC2.5 (GND), IC3.5 (GND), IC4.5 (GND), IC5.5 (GND), IC6.5 (GND), IC7.5 (GND), IC8.5 (GND), OK1.2 (C), OK2.2 (C), OK3.2 (C), OK4.2 (C), OK5.2 (C), OK6.2 (C), OK7.2 (C), OK8.2 (C), Q1.1 (S), Q1.2 (S), Q3.1 (S), Q3.2 (S), Q5.1 (S), Q5.2 (S), Q7.1 (S), Q7.2 (S), Q10.1 (S), Q10.2 (S), Q12.1 (S), Q12.2 (S), Q14.1 (S), Q14.2 (S), Q16.1 (S), Q16.2 (S), R1.1, R6.1, R7.1, R8.1, R13.1, R14.1, R15.1, R20.1, R21.1, R22.1, R27.1, R28.1, R29.1, R30.1, R34.1, R36.1, R37.1, R41.1, R43.1, R44.1, R48.1, R50.1, R51.1, R55.1, S1.A1 (1), S1.A2 (1), S2.A1 (1), S2.A2 (1), S3.A1 (1), S3.A2 (1), S4.A1 (1), S4.A2 (1), S5.A1 (1), S5.A2 (1), S6.A1 (1), S6.A2 (1), S7.A1 (1), S7.A2 (1), S8.A1 (1), S8.A2 (1), X10.1, X10.2, X10.3, X10.4, X10.5, X10.6, X14.1, X14.2, X14.3, X14.4, X14.5, X14.6, X18.1, X18.2, X18.3, X18.4, X18.5, X18.6, X22.1, X22.2, X22.3, X22.4, X22.5, X22.6, X26.1, X26.2, X26.3, X26.4, X26.5, X26.6, X30.1, X30.2, X30.3, X30.4, X30.5, X30.6, X34.1, X34.2, X34.3, X34.4, X34.5, X34.6, X38.1, X38.2, X38.3, X38.4, X38.5, X38.6; also elsewhere on the board
I_OUT_1: IC1.7 (VI_OUT); also elsewhere on the board
I_OUT_2: IC2.7 (VI_OUT); also elsewhere on the board
I_OUT_3: IC3.7 (VI_OUT); also elsewhere on the board
I_OUT_4: IC4.7 (VI_OUT); also elsewhere on the board
I_OUT_5: IC5.7 (VI_OUT); also elsewhere on the board
I_OUT_6: IC6.7 (VI_OUT); also elsewhere on the board
I_OUT_7: IC7.7 (VI_OUT); also elsewhere on the board
I_OUT_8: IC8.7 (VI_OUT); also elsewhere on the board
MOSFET_1: R2.1; also elsewhere on the board
MOSFET_2: R9.1; also elsewhere on the board
MOSFET_3: R16.1; also elsewhere on the board
MOSFET_4: R23.1; also elsewhere on the board
MOSFET_5: R35.1; also elsewhere on the board
MOSFET_6: R42.1; also elsewhere on the board
MOSFET_7: R49.1; also elsewhere on the board
MOSFET_8: R56.1; also elsewhere on the board
unnamed: D4.A, F1.1, F1.3 (1), X9.1, X9.2, X9.3, X9.4, X9.5, X9.6
unnamed: D3.A, F1.2, F1.4 (2), IC1.1 (I+), IC1.2 (I+)
unnamed: D4.C, Q2.2 (E)
unnamed: D3.C, Q2.3 (B), R5.2
unnamed: Q2.1 (C), R7.2
unnamed: C1.1, IC1.6 (FILTER)
unnamed: D2.C, R3.2
unnamed: OK1.1 (A), R2.2
unnamed: OK1.4 (COL), R4.1
unnamed: D1.C, D2.A, IC1.3 (I-), IC1.4 (I-), R4.2, X11.1, X11.2, X11.3, X11.4, X11.5, X11.6
unnamed: OK1.3 (EMIT), Q1.3 (G), Q1.4 (G), R1.2
unnamed: D1.A, Q1.5 (D), Q1.6 (D), Q1.7 (D), Q1.8 (D), Q1.9 (D), R3.1, X12.1, X12.2, X12.3, X12.4, X12.5, X12.6
unnamed: D29.A, F8.1, F8.3 (1), X13.1, X13.2, X13.3, X13.4, X13.5, X13.6
unnamed: D30.A, F8.2, F8.4 (2), IC8.3 (I-), IC8.4 (I-)
unnamed: D29.C, Q15.2 (E)
unnamed: D30.C, Q15.3 (B), R52.2
unnamed: Q15.1 (C), R50.2
unnamed: C15.1, IC8.6 (FILTER)
unnamed: D31.C, R54.2
unnamed: OK8.1 (A), R56.2
unnamed: OK8.4 (COL), R53.1
unnamed: D31.A, D32.C, IC8.1 (I+), IC8.2 (I+), R53.2, X15.1, X15.2, X15.3, X15.4, X15.5, X15.6
unnamed: OK8.3 (EMIT), Q16.3 (G), Q16.4 (G), R55.2
unnamed: D32.A, Q16.5 (D), Q16.6 (D), Q16.7 (D), Q16.8 (D), Q16.9 (D), R54.1, X16.1, X16.2, X16.3, X16.4, X16.5, X16.6
unnamed: D8.A, F2.1, F2.3 (1), X17.1, X17.2, X17.3, X17.4, X17.5, X17.6
unnamed: D7.A, F2.2, F2.4 (2), IC2.1 (I+), IC2.2 (I+)
unnamed: D8.C, Q4.2 (E)
unnamed: D7.C, Q4.3 (B), R12.2
unnamed: Q4.1 (C), R14.2
unnamed: C3.1, IC2.6 (FILTER)
unnamed: D6.C, R10.2
unnamed: OK2.1 (A), R9.2
unnamed: OK2.4 (COL), R11.1
unnamed: D5.C, D6.A, IC2.3 (I-), IC2.4 (I-), R11.2, X19.1, X19.2, X19.3, X19.4, X19.5, X19.6
unnamed: OK2.3 (EMIT), Q3.3 (G), Q3.4 (G), R8.2
unnamed: D5.A, Q3.5 (D), Q3.6 (D), Q3.7 (D), Q3.8 (D), Q3.9 (D), R10.1, X20.1, X20.2, X20.3, X20.4, X20.5, X20.6
unnamed: D25.A, F7.1, F7.3 (1), X21.1, X21.2, X21.3, X21.4, X21.5, X21.6
unnamed: D26.A, F7.2, F7.4 (2), IC7.3 (I-), IC7.4 (I-)
unnamed: D25.C, Q13.2 (E)
unnamed: D26.C, Q13.3 (B), R45.2
unnamed: Q13.1 (C), R43.2
unnamed: C13.1, IC7.6 (FILTER)
unnamed: D27.C, R47.2
unnamed: OK7.1 (A), R49.2
unnamed: OK7.4 (COL), R46.1
unnamed: D27.A, D28.C, IC7.1 (I+), IC7.2 (I+), R46.2, X23.1, X23.2, X23.3, X23.4, X23.5, X23.6
unnamed: OK7.3 (EMIT), Q14.3 (G), Q14.4 (G), R48.2
unnamed: D28.A, Q14.5 (D), Q14.6 (D), Q14.7 (D), Q14.8 (D), Q14.9 (D), R47.1, X24.1, X24.2, X24.3, X24.4, X24.5, X24.6
unnamed: D12.A, F3.1, F3.3 (1), X25.1, X25.2, X25.3, X25.4, X25.5, X25.6
unnamed: D11.A, F3.2, F3.4 (2), IC3.1 (I+), IC3.2 (I+)
unnamed: D12.C, Q6.2 (E)
unnamed: D11.C, Q6.3 (B), R19.2
unnamed: Q6.1 (C), R21.2
unnamed: C5.1, IC3.6 (FILTER)
unnamed: D10.C, R17.2
unnamed: OK3.1 (A), R16.2
unnamed: OK3.4 (COL), R18.1
unnamed: D9.C, D10.A, IC3.3 (I-), IC3.4 (I-), R18.2, X27.1, X27.2, X27.3, X27.4, X27.5, X27.6
unnamed: OK3.3 (EMIT), Q5.3 (G), Q5.4 (G), R15.2
unnamed: D9.A, Q5.5 (D), Q5.6 (D), Q5.7 (D), Q5.8 (D), Q5.9 (D), R17.1, X28.1, X28.2, X28.3, X28.4, X28.5, X28.6
unnamed: D21.A, F6.1, F6.3 (1), X29.1, X29.2, X29.3, X29.4, X29.5, X29.6
unnamed: D22.A, F6.2, F6.4 (2), IC6.3 (I-), IC6.4 (I-)
unnamed: D21.C, Q11.2 (E)
unnamed: D22.C, Q11.3 (B), R38.2
unnamed: Q11.1 (C), R36.2
unnamed: C11.1, IC6.6 (FILTER)
unnamed: D23.C, R40.2
unnamed: OK6.1 (A), R42.2
unnamed: OK6.4 (COL), R39.1
unnamed: D23.A, D24.C, IC6.1 (I+), IC6.2 (I+), R39.2, X31.1, X31.2, X31.3, X31.4, X31.5, X31.6
unnamed: OK6.3 (EMIT), Q12.3 (G), Q12.4 (G), R41.2
unnamed: D24.A, Q12.5 (D), Q12.6 (D), Q12.7 (D), Q12.8 (D), Q12.9 (D), R40.1, X32.1, X32.2, X32.3, X32.4, X32.5, X32.6
unnamed: D16.A, F4.1, F4.3 (1), X33.1, X33.2, X33.3, X33.4, X33.5, X33.6
unnamed: D15.A, F4.2, F4.4 (2), IC4.1 (I+), IC4.2 (I+)
unnamed: D16.C, Q8.2 (E)
unnamed: D15.C, Q8.3 (B), R26.2
unnamed: Q8.1 (C), R28.2
unnamed: C7.1, IC4.6 (FILTER)
unnamed: D14.C, R24.2
unnamed: OK4.1 (A), R23.2
unnamed: OK4.4 (COL), R25.1
unnamed: D13.C, D14.A, IC4.3 (I-), IC4.4 (I-), R25.2, X35.1, X35.2, X35.3, X35.4, X35.5, X35.6
unnamed: OK4.3 (EMIT), Q7.3 (G), Q7.4 (G), R22.2
unnamed: D13.A, Q7.5 (D), Q7.6 (D), Q7.7 (D), Q7.8 (D), Q7.9 (D), R24.1, X36.1, X36.2, X36.3, X36.4, X36.5, X36.6
unnamed: D17.A, F5.1, F5.3 (1), X37.1, X37.2, X37.3, X37.4, X37.5, X37.6
unnamed: D18.A, F5.2, F5.4 (2), IC5.3 (I-), IC5.4 (I-)
unnamed: D17.C, Q9.2 (E)
unnamed: D18.C, Q9.3 (B), R31.2
unnamed: Q9.1 (C), R29.2
unnamed: C9.1, IC5.6 (FILTER)
unnamed: D19.C, R33.2
unnamed: OK5.1 (A), R35.2
unnamed: OK5.4 (COL), R32.1
unnamed: D19.A, D20.C, IC5.1 (I+), IC5.2 (I+), R32.2, X39.1, X39.2, X39.3, X39.4, X39.5, X39.6
unnamed: OK5.3 (EMIT), Q10.3 (G), Q10.4 (G), R34.2
unnamed: D20.A, Q10.5 (D), Q10.6 (D), Q10.7 (D), Q10.8 (D), Q10.9 (D), R33.1, X40.1, X40.2, X40.3, X40.4, X40.5, X40.6
SW_1: S1.B1 (2), S1.B2 (2); also elsewhere on the board
SW_2: S2.B1 (2), S2.B2 (2); also elsewhere on the board
SW_3: S3.B1 (2), S3.B2 (2); also elsewhere on the board
SW_4: S4.B1 (2), S4.B2 (2); also elsewhere on the board
SW_5: S5.B1 (2), S5.B2 (2); also elsewhere on the board
SW_6: S6.B1 (2), S6.B2 (2); also elsewhere on the board
SW_7: S7.B1 (2), S7.B2 (2); also elsewhere on the board
SW_8: S8.B1 (2), S8.B2 (2); also elsewhere on the board
VCC: C2.1, C4.1, C6.1, C8.1, C10.1, C12.1, C14.1, C16.1, IC1.8 (VCC), IC2.8 (VCC), IC3.8 (VCC), IC4.8 (VCC), IC5.8 (VCC), IC6.8 (VCC), IC7.8 (VCC), IC8.8 (VCC); also elsewhere on the board
V_OUT_1: R5.1, R6.2; also elsewhere on the board
V_OUT_2: R12.1, R13.2; also elsewhere on the board
V_OUT_3: R19.1, R20.2; also elsewhere on the board
V_OUT_4: R26.1, R27.2; also elsewhere on the board
V_OUT_5: R30.2, R31.1; also elsewhere on the board
V_OUT_6: R37.2, R38.1; also elsewhere on the board
V_OUT_7: R44.2, R45.1; also elsewhere on the board
V_OUT_8: R51.2, R52.1; also elsewhere on the board

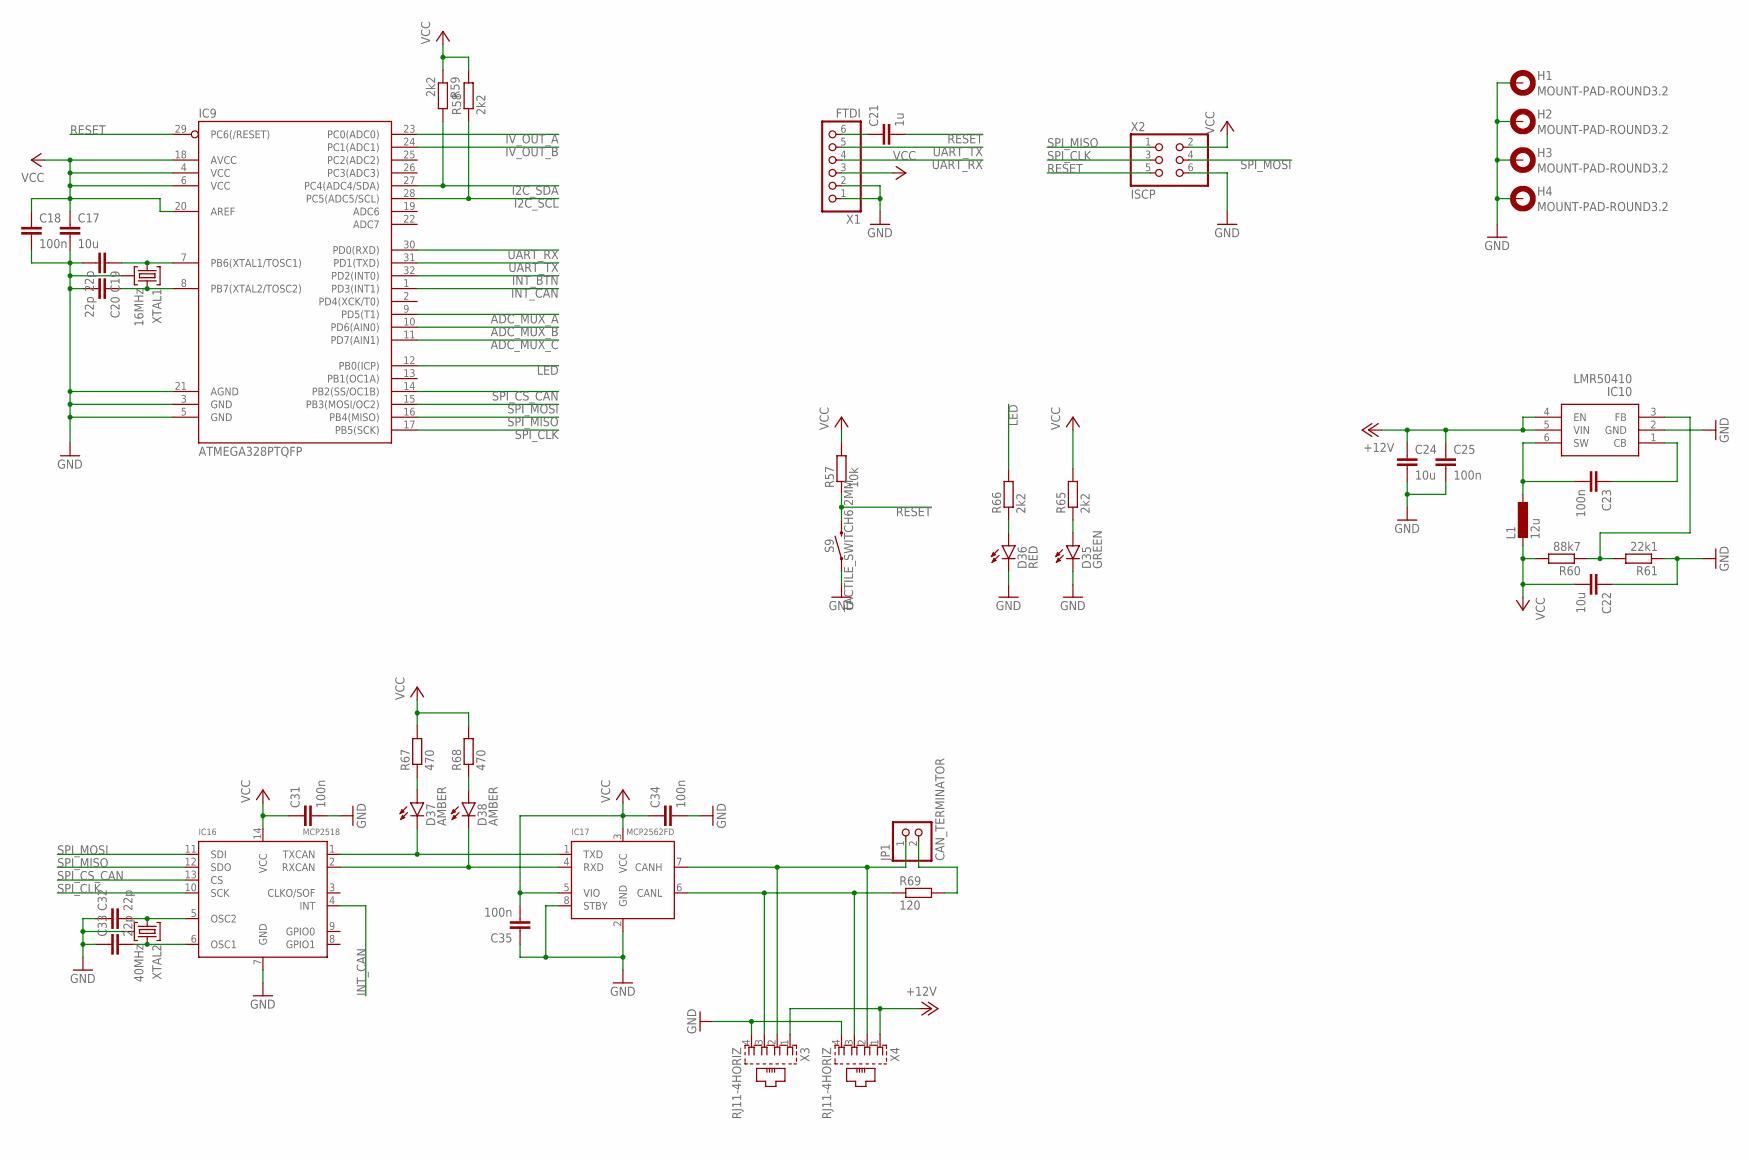
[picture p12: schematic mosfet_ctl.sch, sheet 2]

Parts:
C17, C22, C24: 10u; C1206
C18, C23, C25, C31, C34, C35: 100n; C0805
C19, C20, C32, C33: 22p; C0805
C21: 1u; C0805
D35: GREEN; CHIPLED_1206
D36: RED; CHIPLED_1206
D37, D38: AMBER; CHIPLED_1206
H1, H2, H3, H4: MOUNT-PAD-ROUND3.2; 3,2-PAD
IC9: ATMEGA328PTQFP; TQFP32_0.8MM_7X7MM
IC10: LMR50410; SOT23-6
IC16: MCP2518; SO14
IC17: MCP2562FD; SO08
JP1: CAN_TERMINATOR; 1X02
L1: 12u; L_7.3MM
R57: 10k; R0805
R58, R59, R65, R66: 2k2; R0805
R60: 88k7; R0805
R61: 22k1; R0805
R67, R68: 470; R0805
R69: 120; R0805
S9: TACTILE_SWITCH6.2MM; TACTILE_SWITCH_SMD_6.2MM
X1: FTDI; 1X06
X2: ISCP; 2X03
X3, X4: RJ11-4HORIZ; RJ11-4_HORIZ
XTAL1: 16MHz; XTAL_5.0X3.2_4
XTAL2: 40MHz; XTAL_5.0X3.2_4

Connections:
+12V: C24.1, C25.1, IC10.4 (EN), IC10.5 (VIN), X3.1, X4.1
ADC_MUX_A: IC9.9 (PD5(T1)); also elsewhere on the board
ADC_MUX_B: IC9.10 (PD6(AIN0)); also elsewhere on the board
ADC_MUX_C: IC9.11 (PD7(AIN1)); also elsewhere on the board
GND: C17.2, C18.2, C19.2, C20.2, C22.1, C24.2, C25.2, C31.2, C32.1, C33.1, C34.2, C35.1, D35.C, D36.C, H1.B3,2, H1.P$1, H1.P$2, H1.P$3, H1.P$4, H1.P$5, H1.P$6, H1.P$7, H1.P$8, H2.B3,2, H2.P$1, H2.P$2, H2.P$3, H2.P$4, H2.P$5, H2.P$6, H2.P$7, H2.P$8, H3.B3,2, H3.P$1, H3.P$2, H3.P$3, H3.P$4, H3.P$5, H3.P$6, H3.P$7, H3.P$8, H4.B3,2, H4.P$1, H4.P$2, H4.P$3, H4.P$4, H4.P$5, H4.P$6, H4.P$7, H4.P$8, IC9.3 (GND), IC9.5 (GND), IC9.21 (AGND), IC10.2 (GND), IC16.7 (GND), IC17.2 (GND), IC17.8 (STBY), R61.1, S9.A1 (1), S9.A2 (1), X1.1, X1.2, X2.6, X3.4, X4.4, XTAL1.2, XTAL1.4 (2), XTAL2.2, XTAL2.4 (2); also elsewhere on the board
I2C_SCL: IC9.28 (PC5(ADC5/SCL)), R58.1; also elsewhere on the board
I2C_SDA: IC9.27 (PC4(ADC4/SDA)), R59.2; also elsewhere on the board
INT_BTN: IC9.32 (PD2(INT0)); also elsewhere on the board
INT_CAN: IC9.1 (PD3(INT1)), IC16.4 (INT)
IV_OUT_A: IC9.23 (PC0(ADC0)); also elsewhere on the board
IV_OUT_B: IC9.24 (PC1(ADC1)); also elsewhere on the board
LED: IC9.12 (PB0(ICP)), R66.2
unnamed: D36.A, R66.1
unnamed: C19.1, IC9.7 (PB6(XTAL1/TOSC1)), XTAL1.1
unnamed: C20.1, IC9.8 (PB7(XTAL2/TOSC2)), XTAL1.3
unnamed: D35.A, R65.1
unnamed: C21.1, X1.6
unnamed: IC17.6 (CANL), R69.1, X3.3, X4.3
unnamed: IC17.7 (CANH), JP1.1, X3.2, X4.2
unnamed: D37.C, IC16.1 (TXCAN), IC17.1 (TXD)
unnamed: D38.C, IC16.2 (RXCAN), IC17.4 (RXD)
unnamed: C32.2, IC16.5 (OSC2), XTAL2.1
unnamed: C33.2, IC16.6 (OSC1), XTAL2.3
unnamed: D37.A, R67.1
unnamed: D38.A, R68.1
unnamed: JP1.2, R69.2
unnamed: C23.2, IC10.6 (SW), L1.1
unnamed: C23.1, IC10.1 (CB)
unnamed: IC10.3 (FB), R60.1, R61.2
RESET: C21.2, IC9.29 (PC6(/RESET)), R57.1, S9.B1 (2), S9.B2 (2), X2.5; also elsewhere on the board
SPI_CLK: IC9.17 (PB5(SCK)), IC16.10 (SCK), X2.3
SPI_CS_CAN: IC9.14 (PB2(SS/OC1B)), IC16.13 (CS)
SPI_MISO: IC9.16 (PB4(MISO)), IC16.12 (SDO), X2.1
SPI_MOSI: IC9.15 (PB3(MOSI/OC2)), IC16.11 (SDI), X2.4
UART_RX: IC9.30 (PD0(RXD)), X1.4
UART_TX: IC9.31 (PD1(TXD)), X1.5
VCC: C17.1, C18.1, C22.2, C31.1, C34.1, C35.2, IC9.4 (VCC), IC9.6 (VCC), IC9.18 (AVCC), IC9.20 (AREF), IC16.14 (VCC), IC17.3 (VCC), IC17.5 (VIO), L1.2, R57.2, R58.2, R59.1, R60.2, R65.2, R67.2, R68.2, X1.3, X2.2; also elsewhere on the board


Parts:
C26, C27, C28, C29, C30: 100n; C0805
D33, D34: 1N4148; SOD123
IC11, IC14, IC15: MCP23008; SO18W
IC12, IC13: 4051; SO16
R62, R63, R64: 10k; R0805
S10: SWITCH_DIL08; CTS-219-08

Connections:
ADC_MUX_A: IC12.11 (A), IC13.11 (A); also elsewhere on the board
ADC_MUX_B: IC12.10 (B), IC13.10 (B); also elsewhere on the board
ADC_MUX_C: IC12.9 (C), IC13.9 (C); also elsewhere on the board
GND: C26.1, C27.2, C28.2, C29.1, C30.1, IC11.3 (A2), IC11.4 (A1), IC11.9 (GND), IC12.7 (VEE), IC12.8 (GND), IC13.7 (VEE), IC13.8 (GND), IC14.3 (A2), IC14.4 (A1), IC14.5 (A0), IC14.9 (GND), IC15.3 (A2), IC15.9 (GND), S10.9, S10.10, S10.11, S10.12, S10.13, S10.14, S10.15, S10.16; also elsewhere on the board
I2C_SCL: IC11.1 (SCL), IC14.1 (SCL), IC15.1 (SCL); also elsewhere on the board
I2C_SDA: IC11.2 (SDA), IC14.2 (SDA), IC15.2 (SDA); also elsewhere on the board
INT_BTN: D33.C, D34.C; also elsewhere on the board
IV_OUT_A: IC13.3 (X); also elsewhere on the board
IV_OUT_B: IC12.3 (X); also elsewhere on the board
I_OUT_1: IC12.13 (X0); also elsewhere on the board
I_OUT_2: IC12.15 (X2); also elsewhere on the board
I_OUT_3: IC12.2 (X6); also elsewhere on the board
I_OUT_4: IC12.5 (X5); also elsewhere on the board
I_OUT_5: IC13.1 (X4); also elsewhere on the board
I_OUT_6: IC13.4 (X7); also elsewhere on the board
I_OUT_7: IC13.12 (X3); also elsewhere on the board
I_OUT_8: IC13.14 (X1); also elsewhere on the board
MOSFET_1: IC14.14 (GPIO4); also elsewhere on the board
MOSFET_2: IC14.15 (GPIO5); also elsewhere on the board
MOSFET_3: IC14.16 (GPIO6); also elsewhere on the board
MOSFET_4: IC14.17 (GPIO7); also elsewhere on the board
MOSFET_5: IC14.10 (GPIO0); also elsewhere on the board
MOSFET_6: IC14.11 (GPIO1); also elsewhere on the board
MOSFET_7: IC14.12 (GPIO2); also elsewhere on the board
MOSFET_8: IC14.13 (GPIO3); also elsewhere on the board
unnamed: IC11.5 (A0), R62.1
unnamed: IC15.5 (A0), R64.1
unnamed: IC15.4 (A1), R63.1
unnamed: IC15.10 (GPIO0), S10.1
unnamed: IC15.11 (GPIO1), S10.2
unnamed: IC15.12 (GPIO2), S10.3
unnamed: IC15.13 (GPIO3), S10.4
unnamed: IC15.14 (GPIO4), S10.5
unnamed: IC15.15 (GPIO5), S10.6
unnamed: IC15.16 (GPIO6), S10.7
unnamed: IC15.17 (GPIO7), S10.8
unnamed: D33.A, IC11.8 (INT)
unnamed: D34.A, IC15.8 (INT)
RESET: IC11.6 (RESET), IC14.6 (RESET), IC15.6 (RESET); also elsewhere on the board
SW_1: IC11.17 (GPIO7); also elsewhere on the board
SW_2: IC11.16 (GPIO6); also elsewhere on the board
SW_3: IC11.15 (GPIO5); also elsewhere on the board
SW_4: IC11.14 (GPIO4); also elsewhere on the board
SW_5: IC11.13 (GPIO3); also elsewhere on the board
SW_6: IC11.12 (GPIO2); also elsewhere on the board
SW_7: IC11.11 (GPIO1); also elsewhere on the board
SW_8: IC11.10 (GPIO0); also elsewhere on the board
VCC: C26.2, C27.1, C28.1, C29.2, C30.2, IC11.18 (VCC), IC12.16 (VCC), IC13.16 (VCC), IC14.18 (VCC), IC15.18 (VCC), R62.2, R63.2, R64.2; also elsewhere on the board
V_OUT_1: IC12.12 (X3); also elsewhere on the board
V_OUT_2: IC12.14 (X1); also elsewhere on the board
V_OUT_3: IC12.1 (X4); also elsewhere on the board
V_OUT_4: IC12.4 (X7); also elsewhere on the board
V_OUT_5: IC13.2 (X6); also elsewhere on the board
V_OUT_6: IC13.5 (X5); also elsewhere on the board
V_OUT_7: IC13.13 (X0); also elsewhere on the board
V_OUT_8: IC13.15 (X2); also elsewhere on the board



Board: 2 copper layers, 190.5 x 147.3 mm, 245 parts (37 on the bottom side), 178 nets.

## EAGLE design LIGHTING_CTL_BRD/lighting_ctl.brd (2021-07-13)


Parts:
C1, C3, C8, C11, C12, C14, C16: 100n; C0805
C2, C7, C13, C15: 10u; C1206
C4, C5, C9, C10: 22p; C0805
C6: 1u; C0805
D9, D10, D11, D12: LED1206; CHIPLED_1206
H1, H2, H3, H4: MOUNT-PAD-ROUND3.2; 3,2-PAD
IC1: ATMEGA328PTQFP; TQFP32_0.8MM_7X7MM
IC2: MCP23008; SO18W
IC3: PCA9865TSSOP28; TSSOP28
IC4: MCP2518; SO14
IC5: MCP2562FD; SO08
IC6: LMR50410; SOT23-6
JP1: PINHD-1X2; 1X02
L1: 12u; L_7.3MM
R33, R34: 10k; R0805
R35, R36: 2k2; R0805
R37, R38, R39, R40: 470; R0805
R41: 22k1; R0805
R42: 88k7; R0805
R43: 120; R0805
S9: TACTILE_SWITCH6.2MM; TACTILE_SWITCH_SMD_6.2MM
X1, X2: RJ11-4HORIZ; RJ11-4_HORIZ
X3: PINHD-2X3; 2X03
X4: PINHD-1X6; 1X06
XTAL1: 16MHz; XTAL_5.0X3.2_4
XTAL2: 40MHz; XTAL_5.0X3.2_4

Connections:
+12V: C15.1, C16.1, IC6.4 (EN), IC6.5 (VIN), X1.1, X2.1
GND: C1.2, C2.2, C3.2, C4.2, C5.2, C7.1, C8.2, C9.1, C10.1, C11.2, C12.1, C13.1, C15.2, C16.2, D9.C, D10.C, H1.B3,2, H1.P$1, H1.P$2, H1.P$3, H1.P$4, H1.P$5, H1.P$6, H1.P$7, H1.P$8, H2.B3,2, H2.P$1, H2.P$2, H2.P$3, H2.P$4, H2.P$5, H2.P$6, H2.P$7, H2.P$8, H3.B3,2, H3.P$1, H3.P$2, H3.P$3, H3.P$4, H3.P$5, H3.P$6, H3.P$7, H3.P$8, H4.B3,2, H4.P$1, H4.P$2, H4.P$3, H4.P$4, H4.P$5, H4.P$6, H4.P$7, H4.P$8, IC1.3 (GND), IC1.5 (GND), IC1.21 (AGND), IC2.3 (A2), IC2.4 (A1), IC2.5 (A0), IC2.9 (GND), IC3.1 (A0), IC3.2 (A1), IC3.3 (A2), IC3.4 (A3), IC3.5 (A4), IC3.14 (GND), IC3.24 (A5), IC3.25 (EXTCLK), IC4.7 (GND), IC5.2 (GND), IC5.8 (STBY), IC6.2 (GND), R34.1, R41.1, S9.A1 (1), S9.A2 (1), X1.4, X2.4, X3.6, X4.1, X4.2, XTAL1.2, XTAL1.4 (2), XTAL2.2, XTAL2.4 (2); also elsewhere on the board
I2C_SCL: IC1.28 (PC5(ADC5/SCL)), IC2.1 (SCL), IC3.26 (SCL), R36.1
I2C_SDA: IC1.27 (PC4(ADC4/SDA)), IC2.2 (SDA), IC3.27 (SDA), R35.2
IND_1: IC3.22 (PWM15); also elsewhere on the board
IND_2: IC3.21 (PWM14); also elsewhere on the board
IND_3: IC3.20 (PWM13); also elsewhere on the board
IND_4: IC3.19 (PWM12); also elsewhere on the board
IND_5: IC3.18 (PWM11); also elsewhere on the board
IND_6: IC3.17 (PWM10); also elsewhere on the board
IND_7: IC3.16 (PWM9); also elsewhere on the board
IND_8: IC3.15 (PWM8); also elsewhere on the board
INT_BTN: IC1.32 (PD2(INT0)), IC2.8 (INT)
INT_CAN: IC1.1 (PD3(INT1)), IC4.4 (INT)
LED: IC1.12 (PB0(ICP)), R38.2
unnamed: IC3.23 (#OE), R34.2
unnamed: D9.A, R37.1
unnamed: C4.1, IC1.7 (PB6(XTAL1/TOSC1)), XTAL1.1
unnamed: C5.1, IC1.8 (PB7(XTAL2/TOSC2)), XTAL1.3
unnamed: D10.A, R38.1
unnamed: C6.1, X4.6
unnamed: C14.2, IC6.6 (SW), L1.1
unnamed: IC6.3 (FB), R41.2, R42.1
unnamed: C14.1, IC6.1 (CB)
unnamed: IC5.6 (CANL), R43.1, X1.3, X2.3
unnamed: IC5.7 (CANH), JP1.1, X1.2, X2.2
unnamed: D11.C, IC4.1 (TXCAN), IC5.1 (TXD)
unnamed: D12.C, IC4.2 (RXCAN), IC5.4 (RXD)
unnamed: C9.2, IC4.5 (OSC2), XTAL2.1
unnamed: C10.2, IC4.6 (OSC1), XTAL2.3
unnamed: D11.A, R39.1
unnamed: D12.A, R40.1
unnamed: JP1.2, R43.2
OPTO_1: IC3.6 (PWM0); also elsewhere on the board
OPTO_2: IC3.7 (PWM1); also elsewhere on the board
OPTO_3: IC3.8 (PWM2); also elsewhere on the board
OPTO_4: IC3.9 (PWM3); also elsewhere on the board
OPTO_5: IC3.10 (PWM4); also elsewhere on the board
OPTO_6: IC3.11 (PWM5); also elsewhere on the board
OPTO_7: IC3.12 (PWM6); also elsewhere on the board
OPTO_8: IC3.13 (PWM7); also elsewhere on the board
RESET: C6.2, IC1.29 (PC6(/RESET)), IC2.6 (RESET), R33.1, S9.B1 (2), S9.B2 (2), X3.5
SEL_1: IC2.17 (GPIO7); also elsewhere on the board
SEL_2: IC2.16 (GPIO6); also elsewhere on the board
SEL_3: IC2.15 (GPIO5); also elsewhere on the board
SEL_4: IC2.14 (GPIO4); also elsewhere on the board
SEL_5: IC2.13 (GPIO3); also elsewhere on the board
SEL_6: IC2.12 (GPIO2); also elsewhere on the board
SEL_7: IC2.11 (GPIO1); also elsewhere on the board
SEL_8: IC2.10 (GPIO0); also elsewhere on the board
SPI_CLK: IC1.17 (PB5(SCK)), IC4.10 (SCK), X3.3
SPI_CS_CAN: IC1.14 (PB2(SS/OC1B)), IC4.13 (CS)
SPI_MISO: IC1.16 (PB4(MISO)), IC4.12 (SDO), X3.1
SPI_MOSI: IC1.15 (PB3(MOSI/OC2)), IC4.11 (SDI), X3.4
UART_RX: IC1.30 (PD0(RXD)), X4.4
UART_TX: IC1.31 (PD1(TXD)), X4.5
VCC: C1.1, C2.1, C3.1, C7.2, C8.1, C11.1, C12.2, C13.2, IC1.4 (VCC), IC1.6 (VCC), IC1.18 (AVCC), IC1.20 (AREF), IC2.18 (VCC), IC3.28 (VDD), IC4.14 (VCC), IC5.3 (VCC), IC5.5 (VIO), L1.2, R33.2, R35.1, R36.2, R37.2, R39.2, R40.2, R42.2, X3.2, X4.3

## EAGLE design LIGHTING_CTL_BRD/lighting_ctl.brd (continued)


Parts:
D1, D2, D3, D4, D5, D6, D7, D8: LED1206; CHIPLED_1206
OK1, OK2, OK3, OK4, OK5, OK6, OK7, OK8: OPTOCOUPLERSO4; SO04
Q1, Q2, Q3, Q4, Q5, Q6, Q7, Q8: MOSFET_N_CHANNELSOT223; SOT223
R1, R2, R3, R4, R5, R6, R7, R8, R9, R10, R11, R12, R13, R14, R15, R16, R17, R18, R19, R20, R21, R22, R23, R24, R25, R26, R27, R28, R29, R30, R31, R32: RESISTOR0805; R0805
S1, S2, S3, S4, S5, S6, S7, S8: TACTILE_SWITCH6.2MM; TACTILE_SWITCH_SMD_6.2MM
X7, X8, X9, X10, X11, X12, X13, X14, X15, X16, X17, X18, X19, X20, X21, X22, X23, X24, X25, X26, X27, X28, X29, X30, X35, X36, X37, X38, X43, X44, X45, X46: KEYSTONE_7788

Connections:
GND: D1.C, D2.C, D3.C, D4.C, D5.C, D6.C, D7.C, D8.C, OK1.2 (C), OK2.2 (C), OK3.2 (C), OK4.2 (C), OK5.2 (C), OK6.2 (C), OK7.2 (C), OK8.2 (C), S1.B1 (2), S1.B2 (2), S2.B1 (2), S2.B2 (2), S3.B1 (2), S3.B2 (2), S4.B1 (2), S4.B2 (2), S5.B1 (2), S5.B2 (2), S6.B1 (2), S6.B2 (2), S7.B1 (2), S7.B2 (2), S8.B1 (2), S8.B2 (2); also elsewhere on the board
IND_1: R1.1; also elsewhere on the board
IND_2: R5.1; also elsewhere on the board
IND_3: R9.1; also elsewhere on the board
IND_4: R13.1; also elsewhere on the board
IND_5: R17.1; also elsewhere on the board
IND_6: R21.1; also elsewhere on the board
IND_7: R25.1; also elsewhere on the board
IND_8: R29.1; also elsewhere on the board
unnamed: OK1.1 (A), R2.2
unnamed: D1.A, R1.2
unnamed: OK1.4 (COL), R3.2
unnamed: R3.1, X7.1, X7.2, X7.3, X7.4, X9.1, X9.2, X9.3, X9.4
unnamed: Q1.2 (D), Q1.4 (D), X10.1, X10.2, X10.3, X10.4
unnamed: OK1.3 (EMIT), Q1.1 (G), R4.2
unnamed: Q1.3 (S), R4.1, X8.1, X8.2, X8.3, X8.4
unnamed: OK3.1 (A), R10.2
unnamed: D3.A, R9.2
unnamed: OK3.4 (COL), R11.2
unnamed: R11.1, X11.1, X11.2, X11.3, X11.4, X13.1, X13.2, X13.3, X13.4
unnamed: Q3.2 (D), Q3.4 (D), X14.1, X14.2, X14.3, X14.4
unnamed: OK3.3 (EMIT), Q3.1 (G), R12.2
unnamed: Q3.3 (S), R12.1, X12.1, X12.2, X12.3, X12.4
unnamed: OK2.1 (A), R6.2
unnamed: D2.A, R5.2
unnamed: OK2.4 (COL), R7.2
unnamed: R7.1, X15.1, X15.2, X15.3, X15.4, X17.1, X17.2, X17.3, X17.4
unnamed: Q2.2 (D), Q2.4 (D), X18.1, X18.2, X18.3, X18.4
unnamed: OK2.3 (EMIT), Q2.1 (G), R8.2
unnamed: Q2.3 (S), R8.1, X16.1, X16.2, X16.3, X16.4
unnamed: OK5.1 (A), R18.2
unnamed: D5.A, R17.2
unnamed: OK5.4 (COL), R19.2
unnamed: R19.1, X19.1, X19.2, X19.3, X19.4, X21.1, X21.2, X21.3, X21.4
unnamed: Q5.2 (D), Q5.4 (D), X22.1, X22.2, X22.3, X22.4
unnamed: OK5.3 (EMIT), Q5.1 (G), R20.2
unnamed: Q5.3 (S), R20.1, X20.1, X20.2, X20.3, X20.4
unnamed: OK4.1 (A), R14.2
unnamed: D4.A, R13.2
unnamed: OK4.4 (COL), R15.2
unnamed: R15.1, X23.1, X23.2, X23.3, X23.4, X25.1, X25.2, X25.3, X25.4
unnamed: Q4.2 (D), Q4.4 (D), X26.1, X26.2, X26.3, X26.4
unnamed: OK4.3 (EMIT), Q4.1 (G), R16.2
unnamed: Q4.3 (S), R16.1, X24.1, X24.2, X24.3, X24.4
unnamed: OK6.1 (A), R22.2
unnamed: D6.A, R21.2
unnamed: OK6.4 (COL), R23.2
unnamed: R23.1, X27.1, X27.2, X27.3, X27.4, X29.1, X29.2, X29.3, X29.4
unnamed: Q6.2 (D), Q6.4 (D), X30.1, X30.2, X30.3, X30.4
unnamed: OK6.3 (EMIT), Q6.1 (G), R24.2
unnamed: Q6.3 (S), R24.1, X28.1, X28.2, X28.3, X28.4
unnamed: OK7.1 (A), R26.2
unnamed: D7.A, R25.2
unnamed: OK7.4 (COL), R27.2
unnamed: R27.1, X35.1, X35.2, X35.3, X35.4, X37.1, X37.2, X37.3, X37.4
unnamed: Q7.2 (D), Q7.4 (D), X38.1, X38.2, X38.3, X38.4
unnamed: OK7.3 (EMIT), Q7.1 (G), R28.2
unnamed: Q7.3 (S), R28.1, X36.1, X36.2, X36.3, X36.4
unnamed: OK8.1 (A), R30.2
unnamed: D8.A, R29.2
unnamed: OK8.4 (COL), R31.2
unnamed: R31.1, X43.1, X43.2, X43.3, X43.4, X45.1, X45.2, X45.3, X45.4
unnamed: Q8.2 (D), Q8.4 (D), X46.1, X46.2, X46.3, X46.4
unnamed: OK8.3 (EMIT), Q8.1 (G), R32.2
unnamed: Q8.3 (S), R32.1, X44.1, X44.2, X44.3, X44.4
OPTO_1: R2.1; also elsewhere on the board
OPTO_2: R6.1; also elsewhere on the board
OPTO_3: R10.1; also elsewhere on the board
OPTO_4: R14.1; also elsewhere on the board
OPTO_5: R18.1; also elsewhere on the board
OPTO_6: R22.1; also elsewhere on the board
OPTO_7: R26.1; also elsewhere on the board
OPTO_8: R30.1; also elsewhere on the board
SEL_1: S1.A1 (1), S1.A2 (1); also elsewhere on the board
SEL_2: S2.A1 (1), S2.A2 (1); also elsewhere on the board
SEL_3: S3.A1 (1), S3.A2 (1); also elsewhere on the board
SEL_4: S4.A1 (1), S4.A2 (1); also elsewhere on the board
SEL_5: S5.A1 (1), S5.A2 (1); also elsewhere on the board
SEL_6: S6.A1 (1), S6.A2 (1); also elsewhere on the board
SEL_7: S7.A1 (1), S7.A2 (1); also elsewhere on the board
SEL_8: S8.A1 (1), S8.A2 (1); also elsewhere on the board



Board: 2 copper layers, 101.6 x 132.1 mm, 146 parts (37 on the bottom side), 113 nets.

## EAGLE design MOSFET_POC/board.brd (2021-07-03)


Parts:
C1, C2: C-EUC0805; C0805
D1: DIODE-SOD123; DIODE_SOD123
D2: DIODE-DO214AC; DO214AC
F1: KEYSTONE_3557-2KEYSTONE_3557-2_0_0; KEYSTONE_3557-2_0
IC1: ACS712; SO08
JP1: PINHD-1X5; 1X05
LED1, LED2: LEDSMT1206; 1206
OK1: TLP283; MINI-FLAT-4
Q1: BC857; SOT23-BEC
Q2: IRF7430D2PACK_HEATSINK; D2PACK_HEATSINK
R1, R2, R3, R4, R5, R6, R7: R-EU_R0805; R0805
X1, X2, X3, X4: 7800

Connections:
GND: C1.1, C2.1, IC1.5 (GND), JP1.5, OK1.2 (C)
I_SENSE_1: IC1.7 (VOUT), JP1.2
MOSFET_1: JP1.4, R7.1
unnamed: F1.1, F1.3, LED1.A, X1.1, X1.2, X1.3, X1.4, X1.5, X1.6
unnamed: LED1.C, Q1.E
unnamed: Q1.C, R1.1
unnamed: Q2.3 (S), R1.2, R3.2, R5.1, X2.1, X2.2, X2.3, X2.4, X2.5, X2.6
unnamed: D2.C, IC1.3 (I-_0), IC1.4 (I-_1), LED2.A, R4.1, X3.1, X3.2, X3.3, X3.4, X3.5, X3.6
unnamed: LED2.C, R6.1
unnamed: D1.A, F1.2, F1.4, IC1.1 (I+_0), IC1.2 (I+_1)
unnamed: D1.C, Q1.B, R2.1
unnamed: C1.2, IC1.6 (FILTER)
unnamed: OK1.4 (COL), R4.2
unnamed: OK1.1 (A), R7.2
unnamed: OK1.3 (EMIT), Q2.1 (G), R5.2
unnamed: D2.A, Q2.2 (D), Q2.4 (D), Q2.5 (D), R6.2, X4.1, X4.2, X4.3, X4.4, X4.5, X4.6
VCC: C2.2, IC1.8 (VCC), JP1.1
V_SENSE_1: JP1.3, R2.2, R3.1


Board: 2 copper layers, 87.6 x 34.3 mm, 23 parts (0 on the bottom side), 18 nets.

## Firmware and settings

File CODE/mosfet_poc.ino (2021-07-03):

void setup() {
  // put your setup code here, to run once:
  pinMode(3, OUTPUT);
  //analogWrite(3, 128);
  digitalWrite(3, 1);
  Serial.begin(115200);
}

void loop() {
  float v_raw = 0, i_raw = 0;

  for (int i = 0; i < 10; i++) {
    v_raw = ((v_raw * i) + analogRead(A0)) / (i + 1);
    i_raw = ((i_raw * i) + analogRead(A1)) / (i + 1);
  }

  float v_in = (((v_raw / 1000.0) * 5.0) / (16.0 / (31 + 16))) * 1.053;
  float i_in = map(abs((i_raw - 511)), 0, 512, 0, 30000);

  Serial.print(v_in);
  Serial.print("V - ");
  Serial.print(i_in);
  Serial.println("ma");

  delay(1000);
}

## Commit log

2021-07-03 Initial load of VANBUS circuits
    [board.brd, board.sch, lighting_ctl.brd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]
2021-07-12 Layout updates for MOSFET & LIGHTING boards. Add new boards REMOTE_SWITCH, CAPACITIVE_SWITCH, VANBUS_HUB
    [capacitive_switch.brd, capacitive_switch.sch, hub.brd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]
2021-07-13 v0.1 Production Run Commit - Including GERBER Files
    [capacitive_switch.brd, capacitive_switch.sch, hub.brd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]
